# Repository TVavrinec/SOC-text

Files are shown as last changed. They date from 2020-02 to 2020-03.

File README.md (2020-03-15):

# SOC-text
samotný text SOČky je v .pdf ostatní soubory jsou pro výrobu tohoto .pdf (s názvem SOČ)
ve složkách jsou pak obrázky které jsou i v práci jako takové a ve složkách jsou samostatně opět pro výrobu souboru .pdf
v přílohách jsou pak podklady k výrobě obsahu práce (podklady k desce a mechanice robota)

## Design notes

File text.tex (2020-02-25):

% !TeX spellcheck = en_US
\documentclass{template/socthesis}

\usepackage{subcaption}
\usepackage{amsmath}
\usepackage{enumitem}
\usepackage{hyperref} % balíček pro hypertextové odkazy

\usepackage{color} % balíček pro obarvování textů
% \color{blue}
\usepackage{xcolor}  % zapne možnost používání barev, mj. pro \definecolor
\definecolor{mygreen}{RGB}{0,150,0} % nastavení barev odkazů 
\definecolor{myblue}{RGB}{0,0,200} 
\definecolor{commentgreen}{RGB}{0,100,0} % nastavení barev pro příklady z C++
\definecolor{deepblue}{rgb}{0,0,0.7}
\definecolor{deepred}{rgb}{0.6,0,0}
\definecolor{deepgreen}{rgb}{0,0.5,0}

\hypersetup{colorlinks=true, linkcolor=myblue, urlcolor=mygreen, citecolor=blue, anchorcolor = magenta,
	linktocpage = true, frenchlinks } % nastavení barvy odkazů 

%\addbibresource{text.bib}

\titlecz{Postav si svého prvního robota}
\titleen{Build your first robot}
\author{Tomáš Vavrinec}
\field{10}
\school{Střední průmyslová škola a Vyšší odborná škola Brno, Sokolská}
\mentor{Mgr.Miroslav Burda}
\mentorstatement{Mgr.Miroslava Burdy}

% Změňte, pokud se liší
%\region{Jihomoravský}
%\placefooter{Brno 2017}

\begin{document}

\maketitle

\makecopyrightstatement{V~Brně}

\makethanks{Děkuji svému školiteli Mgr. Miroslavu Burdovi za obětavou pomoc, podnětné připomínky a nekonečnou trpělivost, kterou mi během práce poskytoval.}

\pagestyle{empty}

\section*{Anotace}

Cílem práce je  vyvinout vhodnou levnou a rozšiřitelnou vzdělávací pomůcku -- řídící desku, která umožňuje názorně předvést vlastnosti senzorů a pohonů a která bude schopná řídit například i amatérské soutěžní roboty nebo školní ukázku výrobní linky. Dále vyvinout snadno dostupného robota, kterého tato řídící deska bude řídit.

Tato práce se zabývá návrhem a výrobou řídící desky Schoolboard a robota Schoolbot a jejich použitím při výuce dětí v zájmovém vzdělávání a při školní výuce předmětů elektroniky, automatizace, programování a dalších. 

\subsection*{Klíčová slova}
SchoolBot; SchoolBoard; robot; vyuka robotiky; řídící deska; ESP32

\vspace{20mm}

\section*{Annotation}

The aim of this work is to develop a suitable cheap and extensible educational tool -- control board, which allows to demonstrate the characteristics of sensors and drives and which will be able to control, for example, amateur competition robots or school demonstration production line. Further, to develop an easily accessible robot to control this control board.

This work concerns with the design and production of the control board named Schoolboard and Schoolbot robot and their use in teaching children in leisure education and in school teaching of electronics, automation, programming and others.

\subsection*{Keywords}
SchoolBot; SchoolBoard; robot; teaching robotics; control board; ESP32

\newpage
\pagestyle{plain}

\tableofcontents % vysází obsah

%%% Začátek práce
\setcounter{figure}{0}
\setcounter{table}{0}
\newpage

\chapter*{Úvod}
\addcontentsline{toc}{chapter}{Úvod} % přidá položku úvod do obsahu
Moje práce má za cíl vytvořit pomůcku (robota) pro praktické seznámení s~elektonikou, robotikou a programováním pro:  

\begin{itemize}
	\item účastníky volnočasových kroužků robotiky, elektroniky a podobných
	\item studenty středních škol, především oborů elektronika, automatizace, robotika, ale i pro předměty informatika nebo fyzika
	\item další začínající zájemce o elektoniku a robotiku. 
\end{itemize}

 Pokud zájemce -- začátečník  o elektroniku a nebo hobby robotiku absolvuje \uv{blikání ledkou}, obvykle chce pokračovat stavbou svého prvního robota (podle hesla: \uv{Ať se to hýbe!}). Když se 
 rozhlédne kudy dál, zjistí, že všechny dostupné možnosti jsou tak či onak dost problematické (viz kapitola \ref{konkurence}). 
 
 Podobná situace nastává ve škole, kdy například funkci probíraných senzorů, enkodérů a podobně někdy není na čem prakticky ukázat. To se týká především situace, kdy učitel chce, aby studenti s robotem sami pracovali, například ve dvojicích.   

Řídící deska \textbf{Schoolboard} a robot \textbf{SchoolBot} jsou primárně navrženy pro volnočasový vzdělávací kroužek robotiky pořádaný na naší škole a jsou určeny pro začátečníky. Jako takoví dávají účastníkům kroužku možnosti, které má prakticky každý soutěžní robot, konkrétně pohon pro pohyb na hřišti, klepeta pro manipulaci s herními prvky a senzory pro samostatnou orientaci na hřišti. 
\newpage

 Takový robot by měl mít: 

\begin{itemize}
	\item \textbf{modulární senzoriku} -- být schopný připojit na sebe různé senzory 
	
	\item \textbf{rozšiřitelnou konstrukci} -- možnost i velké úpravy, změn a rozšíření konstrukce robota, připojení různých pohonů (motory, serva)
	
	\item \textbf{bezdrátové řízení}
	
	\item dostatečně \textbf{tuhou konstrukci}
	
	\item  \textbf{možnost programovat v C++}, které je dnes standardem v této oblasti
	
	\item a hlavně: \underline{\textbf{nízkou pořizovací cenu}}, protože bez ní jsou všechny ostatní příznivé vlastnosti bohužel téměř na nic 
	
\end{itemize}

Ideálně by si takového robota účastníci kroužku měli být schopni postavit, spájet a oživit (podle pokynů vedoucího) sami. 

%\section{SchoolBot}

%\section{BlackBox}
%BlackBox je elektronicky ovládaný trezor, který je s vhodnou úpravou schopen i jezdit na vlastních kolech. Pro začátečníky má i čistě mechanickou variantu bez elektroniky, ta však muže sloužit jen jako trezor a nemá ostatní možnosti které má až elektronická varianta. Elektronická varianta má rozmanité senzory, díky kterým muže nabývat různých podob od trezor po hodiny.

\newpage

\chapter{Proč vytvářet vlastní roboty?}

Proč vlastně vytvářet vlastní elektroniku i mechaniku, když je na trhu tolik různých robotu a vozítek? Konkurenční roboti, kteří se běžně prodávají, jsou totiž většinou velmi drazí a často nemají ani moc možností. Například známé LEGO Mindstorms, u kterého se cena základní sady pohybuje nad sedmi tisíci korunami \cite{lego_cena},
 je vzhledem ke svým možnostem ohromně předražené.
 
%zmizela poznámka o dokumentaci (nebyla tak pravdivá jak bych chtěl abych jí zde nechal [ splnoval by to asi jen Asuro a možná OZOBOT s Edisnem])

\newpage

\section{Konkurence} \label{konkurence}

\subsection{LEGO Mindstorms EV3}

\begin{figure}[h]
	
	\centering
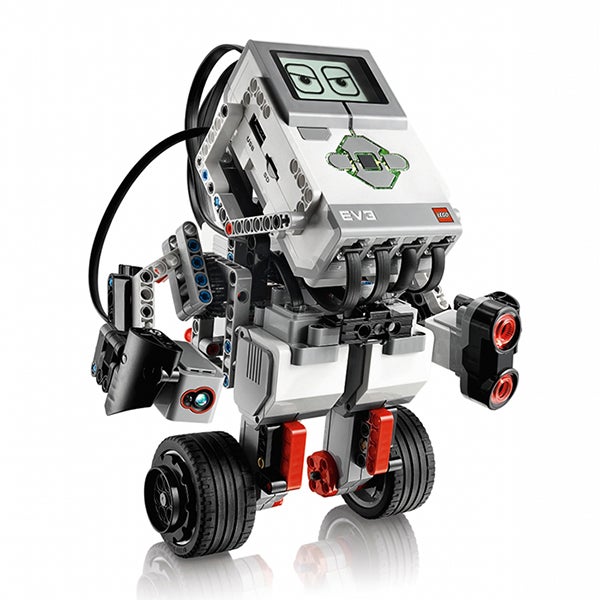
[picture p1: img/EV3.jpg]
	
	\caption{LEGO Mindstorm}~\cite{lego_obr}
	
\end{figure}

LEGO Mindstorms \cite{lego} je známé svou jednoduchostí. Základní roboti se s touto sadou dají sestavit velmi rychle, což poskytuje hlavně začátečníkům motivaci, neboť již s poměrně malým úsilím sestaví něco, co na první pohled funguje. Dílky LEGa však nejsou moc pevné a konstrukce z nich postavená jich tedy vyžaduje velké množství, aby byla obstojně tuhá. To se samozřejmě dá vyřešit tím, že si člověk udělá konstrukci z jiného materiálu, potom ale odpadá výhoda jednoduchosti stavby.

Možnosti robota se z velké části odvíjí od senzoriky. LEGO trpí na nedostatek senzorů a ještě vic na melí počet konektorů. Nejen, že v základní sadě je, krom tlačítka, od každého sensoru jen jeden kus. Ale ani kostka, řídící centrum LEGa, nedokáže číst víc než čtyři senzory naráz. Je pravda že LEGO má možnost spojovat několik kostek dohromady, to však samozřejmě vyžaduje mít jich víc, což je při ceně LEGa poměrně drahé.

LEGO má své vlastní programovací prostředí, které je většinou pro začá\-teč\-ní\-ky dobré. Jakmile však uživatel chce vytvářet vetší program, prostředí velmi rychle ztratí užitečnost. Vetší programy jsou v grafickém prostředí velmi nepřehledné. Navíc prostředí LEGa může být u větších programů nestabilní. Existují však i prostředí, ze kterých se dá lego programovat textově, například v jazyku C++, což je u složitějších programu přehlednější a také méně náročné pro počítač.

\subsection{Mbot} 

\begin{figure}[h]
	
	\centering
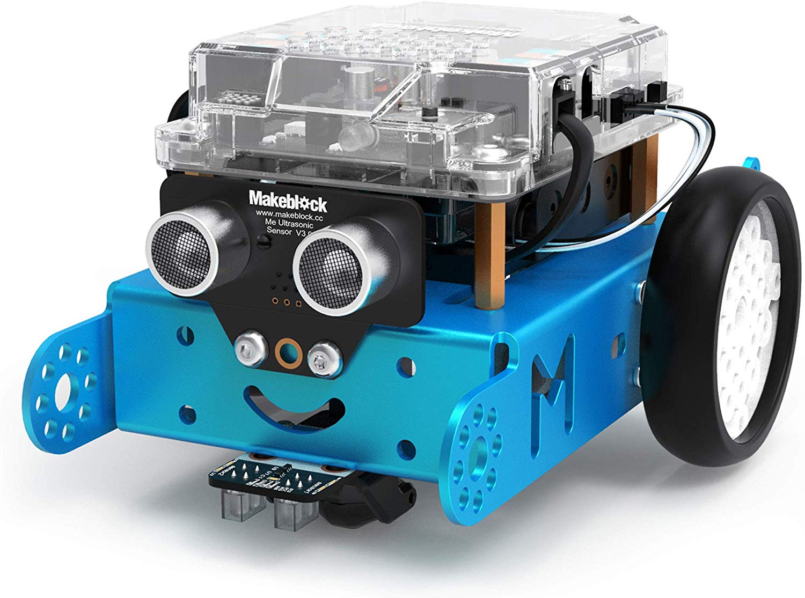
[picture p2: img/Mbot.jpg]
	
	\caption{Mbot} 
	\cite{Mbot_obr}
	
\end{figure}

Mbot \cite{Mbot} je oproti LEGu daleko levnější (cena se pohybuje kolem osmnácti set korun za kus) ale trpí stejným, nebo i větším, nedostatkem konektoru pro sensory. 

Co se konstrukce týče, problémy s pevností u Mbota není, ale zase se nedá snadno upravit. Konstrukce je totiž hliníková, což je v pořádku, pokud není potřeba konstrukci výrazně upravovat. Robota je ale většinou třeba přizpůsobit konkrétnímu užití.
 Ze zkušenosti se nejvíce osvědčilo dřevo, které se dá jednoduše upravovat bez větší námahy a zároveň není problém z něj udělat dostatečně tuhou konstrukci. Hliník se však tak lehce ručně upravovat nedá.
 
Mbot je založen na procesoru ATmega328, což je stejný procesor, jaký se používá i u velice známého Arduina.
To znamená, že některé programy, které jsou napsané pro Arduino, je možné spustit i zde.

\subsection{Edison V2.0}

\begin{figure}[h]
	
	\centering
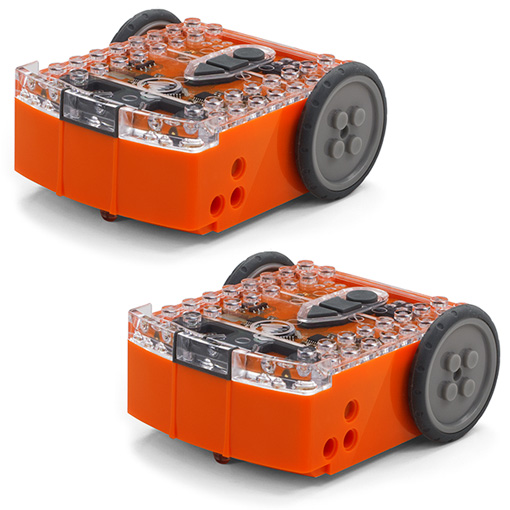
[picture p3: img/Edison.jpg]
	
	\caption{Edison V2.0} 
	\cite{Edison_obr}
	
\end{figure}

Edison \cite{Edison1}, \cite{Edison2} je velmi podobný LEGu a má i podobné problémy. Opět nedisponuje velkým počtem senzorů, ale oproti LEGu je alespoň daleko levnější \cite{Edison_cena}. 

Stejně jako LEGO má i Edison vlastní grafické programovací prostředí, bohužel jsem jej nikdy nepoužíval, ale vypadá velmi podobně jako prostředí LEGa. Myslím si proto, že stejně jako prostředí LEGa bude i toto velice dobré na malé prográmky pro děti, ale nevhodné pro obsáhlé programy.

Všechny senzory má Edison uvnitř sebe a nedají se proto dovést na místo, kde je uživatel nejvíc potřebuje. Uživatel se proto musí přizpůsobit rozložení senzorů na řídící jednotce, stejně tak se nedá vyvést ani nic jiného. Jediné, co se dá, je vyměňovat kola (například za nějaké ozubení) a pomocí toho si pak dovést náhon z motoru na potřebné místo.

\newpage

\subsection{OZOBOT }
\begin{figure}[h]
	
	\centering
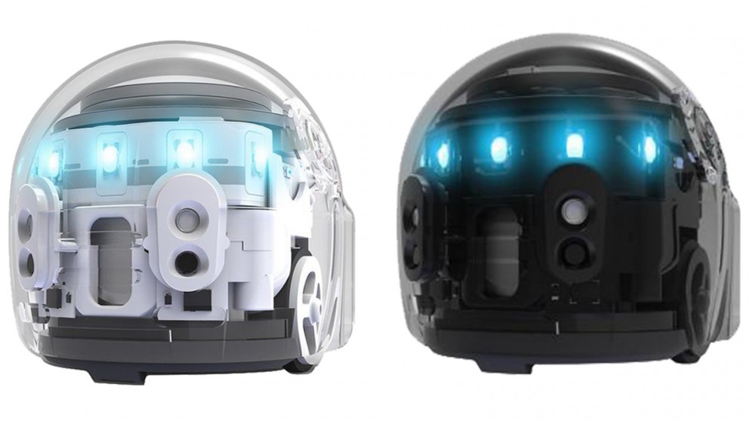
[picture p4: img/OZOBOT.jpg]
	
	\caption{OZOBOT 2.0} 
	\cite{OZOBOT_obr}
	
\end{figure}
Ozobot \cite{OZOBOT1}, \cite{OZOBOT2} je mini robot, z toho vyplývají jeho největší výhody i nevýhody. Například pochopitelně není dělaný na to, aby cokoli vozil nebo jakkoliv stěhoval. Téměř se nedá upravovat, na to ale opět není dělaný. Jeho účel je především jezdit po čáře a vykonávat příkazy na ní zapsané pomocí barevných vzorů. Přes to že se novější verze dají i programovat, jejich funkce jsou pořád mířené do velké míry právě na čáru a barevné příkazy na ní.

\newpage

\subsection{Asuro}
\begin{figure}[h]	
	\centering
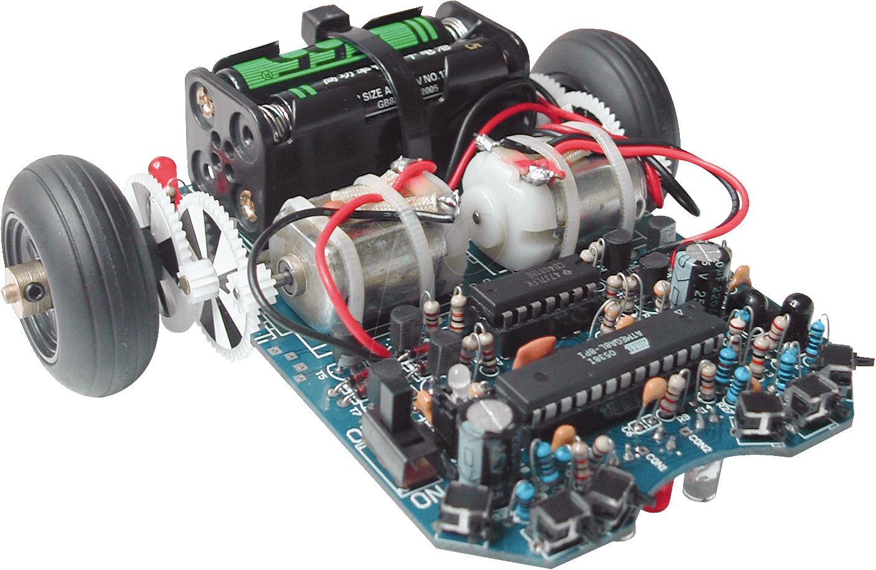
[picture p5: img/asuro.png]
	
	\caption{Asuro} 
	\cite{Asuro_obr}	
\end{figure}
Asuro \cite{Asuro_navod}, \cite{Asuro_cena} je robot postavený kolem základní desky. Jedná se o stavebnici, ale přesto nemá ani jednoduché pomůcky pro možnost přesné stavby. Asuro má mezi koly a motorem převodovku, která se ukládá do jakýchsi ložisek. Ta se bez jakéhokoli zapozicování napájí na plochu desky. Výsledkem je téměř nemožnost uložit kola převodovky přesně.

\newpage

\subsection{Microbit}
%\textbf

\begin{figure}[h]
		
		\centering
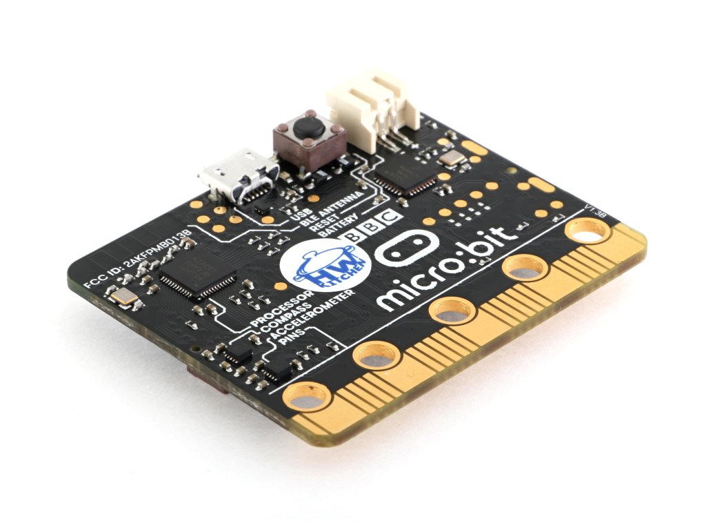
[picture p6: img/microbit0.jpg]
		
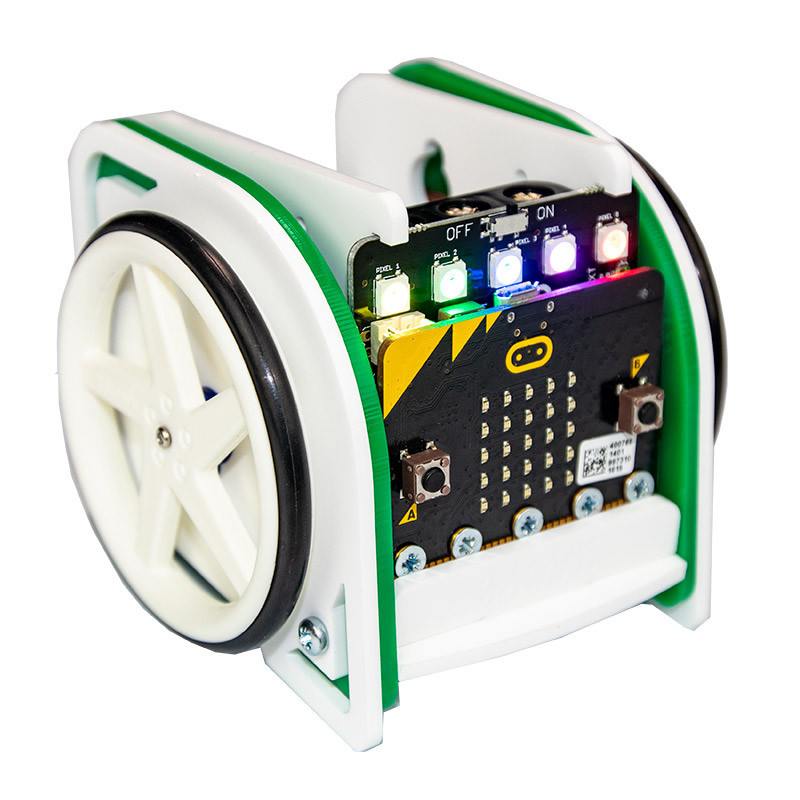
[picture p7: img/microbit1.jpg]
		
		\caption{Microbit \cite{Microbit_obr1}, \cite{Microbit_obr2}} 
		
\end{figure}

Microbit \cite{Microbit1}, \cite{Microbit2}, \cite{Microbit3} je především řídící deska se senzory a výstupními ledkami. Není to primárně vozítko, přestože existují konstrukce, které jsou určené právě pro řízení microbitem. Taková konstrukce však muže využívat pouze serva, nebo musí mít vlastní řízení motoru. Microbit totiž motory řídit edokáže sám, dokáže řídit jen serva, která si silové řízení řeší sama. Toto však není velký problém, protože existuje více různých konstrukcí, které právě toto řeší. 

Microbit má překvapivě docela dost senzorů přímo na základní destičce. Podle mých informací kompas, který je přímo na desce téměř nefunguje, ale vzhledem k tomu, co všechno na sobě malá destička Microbit má, to není až taková tragédie. Kompas je stejně často potřebné dostat co nejdál od zbytku robota, kvůli všemožnému rušení, takže by se i tak dost možná používal jako externí součástka.

Microbit má zároveň matici ledek, na které si uživatel muže zobrazovat, co se mu zlíbí a zároveň se jimi dá i měřit světelnost okolí. Používání led diod jako fotodiod sice není tak přesné, nicméně to jde a je to zajímavé řešení.

Microbit ale nemá zrovna velké množství pinu, které by se daly použít, a především je opět drahý. Cena čisté desky, bez jakéhokoli příslušenství, se pohybuje kolem 500 Kč a za tuto cenu jsem já schopen vyrobit desku, která je schopna operovat i se silovými výstupy (a ještě mi něco zbude).

\subsection{Shrnutí}
Komerční systémy jsou většinou velmi drahé, mívají nedostatek senzorů, mívají měkkou nebo obtížně upravitelnou konstrukci a také nemají moc velký výkon ani přesnost pohonu.

Možná si říkáte, proč mi záleží na tom aby robot pro začátečníky měl všechny tyto možnosti. Vždyť člověku, co nikdy robota nestavěl, by to mohlo být skoro jedno. Ano, ale já chci, aby se na prvním robotu, které si zájemce postaví, dalo stavět dál. Aby bylo vidět, že si z robota, který toho moc neuměl, může uživatel postavit něco, co by třeba mohlo jezdit na soutěže a vyhrávat.

\begin{table}[h]
	\centering
	\begin{tabular}{|l|l|l|l|l|l|l|}
		\hline
		\textbf{robot }			& modulární   & rozšiři- & bezdrátové  & tuhá  & nízká & C++\footnote{Možnost naprogramování robota v C++.} \\
		 & senzorika & telnost & řízení & konstrukce & cena &  \\
		 \hline
		Mbot 			& 0 				& 0 			& 0 			& 1 			& 0			& 0	\\ 
		LEGO\footnote{myšleno LEGO MINDSTORMS} 	& 1/2 				& 1 			& 1 			& 0 			& 0			& 1/2	\\ 
		Edison 			& 0 				& 0 			& 1/2 			& 1/2 			& 1			& 0	\\ 
		OZOBOT			& 0					& 0				& 1 			& 1				& 0			& 0	\\
		Asuro			& 0					& 0				& 0 			& 0				& 0			& 1	\\
		Microbit		& 0					& 1				& 1 			& 1				& 0			& 0	\\
			\textbf{SchoolBot} 		& \textbf{1} 				& \textbf{1} 			& \textbf{1} 			& \textbf{1} 			& \textbf{1} 		& \textbf{1}	\\ 
		\hline
	\end{tabular}
	\begin{center}
		\caption{Srovnání možností dostupných komerčních systémů pro hobby roboty}
	\end{center}
\end{table}

\chapter{SchoolBot}

SchoolBot je komplet, skládající se ze řady jednotlivých dílků, které nebudu popisovat samostatně, ale pro přehlednosti systém rozdělím na elektroniku a~mechaniku.

\section{Elektronika}

Elektronika je především řídící deska SchoolBoard kterou shrnuji v samostatné kapitole \ref{RB3202} a detailně rozebírám v přílohách. Krom desky obsahuje SchoolBot battery pack, motory s enkodéry a inteligentní serva LX15D
\cite{inteligentni_servo_LX15D}, která uvádí do provozu klepeta, nástroj pro manipulaci s objekty při soutěžích, především s herními prvky.

\begin{figure}[h]
	
	\centering
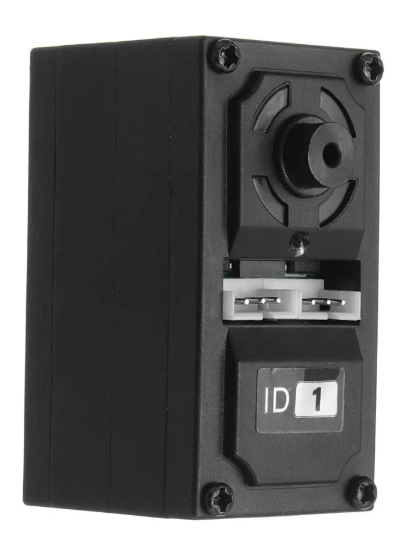
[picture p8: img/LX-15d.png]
	
	\caption{inteligentní servo LX-15d \cite{inteligentni_servo_LX15D}}
	
\end{figure}

\subsection{Battery pack}

Battery pack je sestaven ze dvou li-on baterií 18650, které jsou pomocí DPS spojeny v jeden celek. Připojení do robota je pak zajištováno pomocí dutinek a to každý článek zvlášť, serializují se až po vložení do robota. Důvodem pro vyvádění obou článku zvlášť je nabíjení. To je totiž realizováno pomocí lineárních nabíjecích modulu, které se napájejí z USB a každý článek se nabíjí zvlášť.

Aby se battery pack nedal omylem připojit s opačnou polaritou, je vyřešen tak, že se dá při připojení otočit dvěma způsoby a oba mají správnou polaritu, dokonce i stejné pořadí článků.

\begin{figure}[h]
	\centering
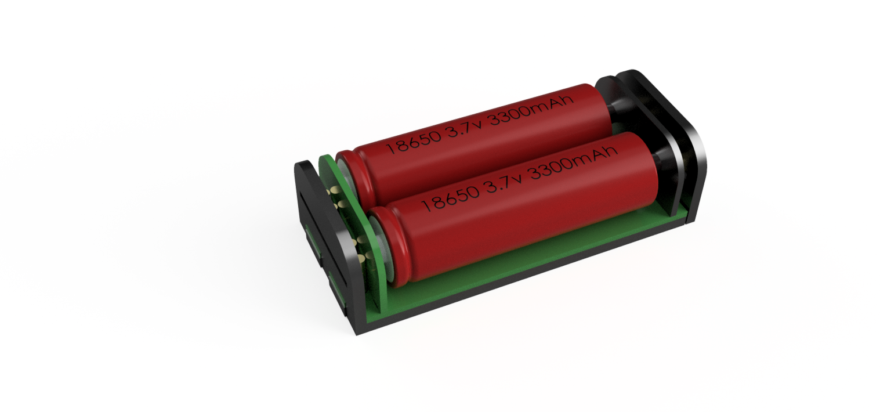
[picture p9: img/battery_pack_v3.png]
	
	\caption{render 3D modelu battery packu}
\end{figure}

\subsection{Motory s enkodéry}

SchoolBot používá levné motory s plastovou převodovkou, které v základu enkodéry nemají. Enkodéry si proto SchoolBot řeší sám, a to pomocí magnetu a dvou Halových sond. Takto vyrobený inkrementální enkodér pak vyhodnocuje procesor na řídící desce.

\newpage

\section{Mechanika}

Mechanika SchoolBota je celá z překližky vypálené pomocí laserového řezáku. Je stavěná kruhově, aby se robot nemohl zaseknout v nějakém rohu a~v~přední části má umístěná klepeta, kterými je robot schopen nabírat a převážet různé objekty. 

\subsection{Uložení kol a motoru}

Kola nejsou jen tak nasazená na motor. Aby se nevyvracela, a tím pádem méně zatěžovala převodovku motoru, jsou z druhé strany podepřena a uchycena k obvodu konstrukce.

Celý motor i s kolem je pak zčásti držen podporou kola, ale především je celý motor vložen do těsné šachty, kde se nemůže otočit ani posunout jiným směrem než vzhůru. Následně je přitlačen palubou, která se přišroubuje čtyřmi šrouby. Takovéto řešení umožnuje jednoduchý přístup k motoru a jeho pevné uchycení.

\begin{figure}[h]
	\centering
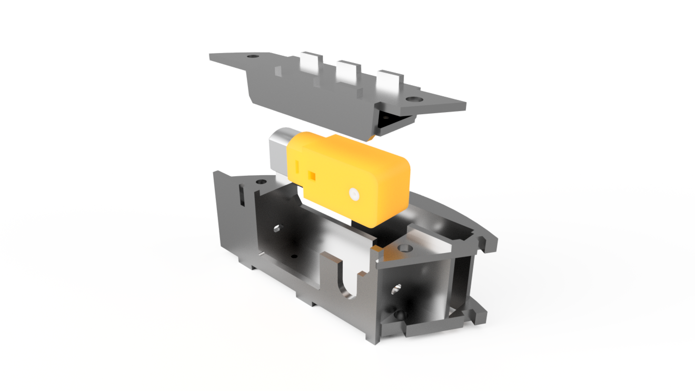
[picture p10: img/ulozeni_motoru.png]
	
	\caption{render 3D modelu motorového lože}
\end{figure}

\newpage

\subsection{Klepeta}
Klepeta jsou postavena tak, aby měla osu otáčení co nejdále od sebe. Protože ve chvíli, kdy robot s otevřenými klepety narazí do mantinelu, musí mít konce klepet k sobě blíž než osy jejich otáčení, aby se klepeta sama zavřela (o mantinel bez potřeby řízení). Z tohoto důvodu jsou serva, na kterých jsou klepeta uložena, posazena co nejdál od sebe, právě aby se klepeta mohla otevřít co nejvíc a u toho si zachovat svojí schopnost zavřít se o mantinel (stěnu).
\begin{figure}[h]
	\centering
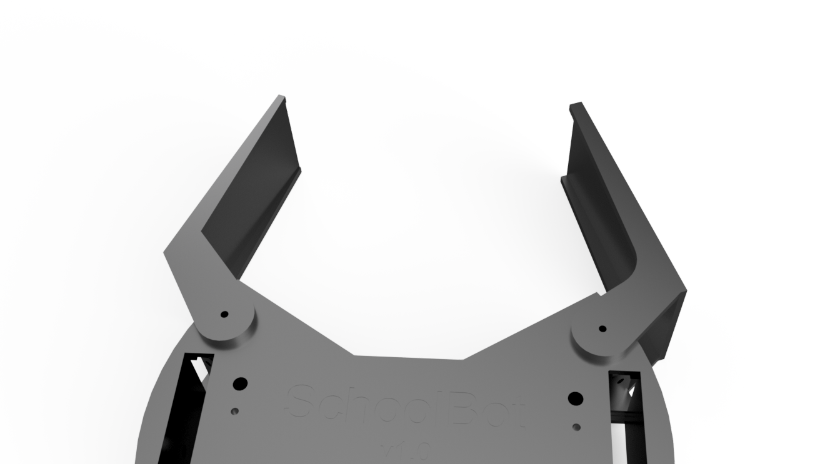
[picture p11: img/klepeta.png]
	
	\caption{renderovaný pohled na klepeta}
\end{figure}

\chapter{SchoolBoard}\label{RB3202}

\ref{RB3202_obr}

\section{Popis desky}

Deska \ref{RB3202l} %todo
má k dispozici

\begin{itemize}
	\item třicetidvoubitový procesor ESP32 s taktovací frekvencí 240~MHz 
	a~na\-pá\-je\-cím napětím 3,3 V 
	\item flash pamětí 4 MB (dělají se i verze s 8 a 16 MB), 520 KB SRAM, WI-Fi, Bluetooth, 28 vstupně výstupních piny, dva ADC převodníky (jeden s 6 piny a druhý s 10 piny), jedním DAC převodníkem s dvěma piny, tři UARTy, dvě SPI, tři I2C(jedno je použito interně pro flash) atd.
	
	\item Motorový driver DRV8833, který umožnuje řídit dva stejnosměrné motory nebo jeden krokový motor.
	
	\item Tři konektory na inteligentní serva LX-15D nebo LX-16A. Deska dokáže řídit až 254 těchto serv. Serva se totiž dokáží řetězit za sebe, ale pokud potřebují větší proud (když podávají větší kroutící moment), ubytek napětí na kabelech je už moc velký, aby serva mohla využít plný výkon. Proto jsou na desce konektory tři a ne jen jeden.
	
	\item Čtyři uživatelská tlačítka.
	
	\item Tři uživatelské LED a jedna LED signalizující zapnutý stav.
	
	\item Možnost měření napětí baterie.
	
	\item Hardwarové řešení startu a vypínání (dá se použít i jako nouzový vypínač). Tlačítka na zapínání a vypínání jsou jak přímo na desce, tak jsou i vyvedena na pinheady pro možnost připojení externího řízení.
	
	\item Konektor na připojení motorů s enkodérem.
	
	\item Deska operuje na napětí 3,3~V, ale aby byla schopná komunikovat i s periferiemi operujícími
	na napětí 5~V, jsou čtyři piny opatřené převodníkem napěťových úrovní.
	Piny IO35, IO32, IO14 a IO12 jsou tedy schopny operovat jak na napětí 3,3~V, tak na 5~V.
	
	Piny jsou teoreticky schopné pracovat i na napětí vyšším, záleží na součástce IM3
	(step-down nebo stabilizátor 7805), která napájí pře\-vod\-ník. Pokud bude IM3 dodávat jiné napětí, bude toto napětí i na 5~V pinech (napětí nesmí klesnout pod 4,5~V jinak procesor nedostane dost proudu).
	
	\item Vyvedení 5~V napájení je na oddělené stabilizaci (součástka IM4) pro možnost napájení jiným napětím.
	
	\item Deska má také vyvedeny všechny piny ESP32, které nejsou spojeny 
	s~hlavní funkcí desky (řízení motorů) a není problematické se o ně starat při bootu ESP32.
	
	\item Schoooboard je možné řetězit a tím pro robota nebo jiné zařízení získat  jednak další výpočetní výkon, jednak další možnosti rozšíření. 
	
	\end{itemize}

\section{Možné periferie}
Vzhledem k tomu že je deska řízena procesorem ESP32, který umožnuje komunikaci po řadě sběrnic a disponuje i svým vlastním AD převodníkem. Je schopna pracovat s velmi rozsáhlou řadou periferií. Díky převodníku na\-pě\-ťo\-vých úrovní navíc umožnuje komunikaci ne jen na 3,3~V (pracovní napětí procesoru) ale i na napětí 5~V (při jiném nastavení jisté součástky[viz přílohy \ref{RB3202-5V}]
 i~jiném napětí vyšším než 3,3~V). 
\subsubsection{Příklady možných senzorů}
\begin{itemize}
	\item Kamera
	\item Ultrazvukový dálkoměr
	\item Infračervený dálkoměr
	\item Laserový dálkoměr
	\item Senzory na sledování čáry
	\item Senzory barev
	\item Gyroskop
	\item Akcelerometr
	\item Kompas
	\item Hodiny reálného času
	\item Teploměr
	\item Barometr
	\item Senzor osvětlení
	\item Vlhkoměr
	\item a mnoho dalších ... 
\end{itemize}

\subsubsection{Příklady jiných periferií}

\begin{itemize}
	\item Inteligentní serva (např. LX15D nebo LX16A)
	\item Inteligentní LED (např. WS2812)
	\item Modelářská serva
	\item Stejnosměrné motory (s rozsahem napětí od 6 do 11~V a proudem do 1~A [při použití silnější verze stejného driveru do 1,5A])
	\item Krokový motor
	\item Obyčejné LED
	\item Elektromagnetické ventily
\end{itemize}

\section{Vývoj}

SchoolBot jsem začal vyvíjet, protože účastníci kurzu robotiky v minulých letech nestíhali za jeden školní rok vytvořit vlastní konstrukci a ještě ji naprogramovat. Přesto, že elektroniku již vyřešenou měli, tak mechanika a~především programování na ně bylo stále příliš. Přitom robotické soutěže jsou \uv{zlatým hřebem} každého školního roku. Proto jsem začal koncem loň\-ské\-ho školního roku 2018/2019 vyvíjet robota, který měl řešit jak elektroniku, tak většinu mechaniky. 

První prototyp mechaniky byl hotový již začátkem letních prázdnin, ale další vývoj pokračoval až o hodně později. První verze totiž vyžadovala jen velmi málo úprav jsem musel dokončit řídící desku, která již sice také měla první prototyp za sebou, ale vyžadovala daleko víc úprav. Již druhá verze desky byla plně provozuschopná a začátkem školního roku 2019/2020 jsme jí začali stavět s účastníky kurzu.

 Ne všichni však chtěli použít mojí konstrukci. Někteří si jí chtěli navrhnout sami a někteří měli tak těžké doplňky, že by je tento robot neuvezl. 
SchoolBota tak letos využil jen jeden ze sedmi týmů.

\section{Kde se deska používá}
Deska se používá ve dvou volnočasových kurzech robotiky a při výuce elektrotechniky a automatizace na naší škole.

\subsection{Školní kroužek robotiky}

Ve školním kurzu robotiky se začalo pracovat se SchoolBoardem koncem října. Účastníci si nejprve zapájeli %(jelikož první verze SchoolBoardu se ještě neosazovala strojově) 
desku a v prosinci si začali navrhovat a~stavět mechanickou konstrukci robota. V té době již byli rozděleni do týmů na soutěž Robotický Den \cite{RD2020}
 v Praze a měli vybranou disciplínu, které se chtěli zúčastnit. Tím pádem již mohli vyvíjet konkrétní instrumenty pro konkrétní úkoly a nemuseli vymýšlet univerzální systémy, které jsou náročné na mechaniku, a především na programování. Díky těmto znalostem některé týmy došly k názoru, že si musí konstrukci opravdu navrhnout samy a nemůžou použít SchoolBot. Robot jednoduše není dost silný, aby uvezl předměty, které samy váží více než dva kilogramy.

Tímto způsobem vzniklo v šesti týmech pět různých robotů, jeden tým (ten šestý) zůstal u SchoolBotu a svou vlastní konstrukci tak nevytvořil. Všichni tito roboti však jsou řízeni SchoolBoardem. 

V jednom případně dokonce dvěma Schoolboardy, protože týmu nestačily dva motory a protože v týmu měli víc desek.

Jejich výsledky ze soutěže bohužel zatím nemám k dispozici protože soutěž se koná až 6 a 7.6.2020 a je tím pádem pro mě ještě v budoucnosti.

\begin{figure}[h]
	\centering
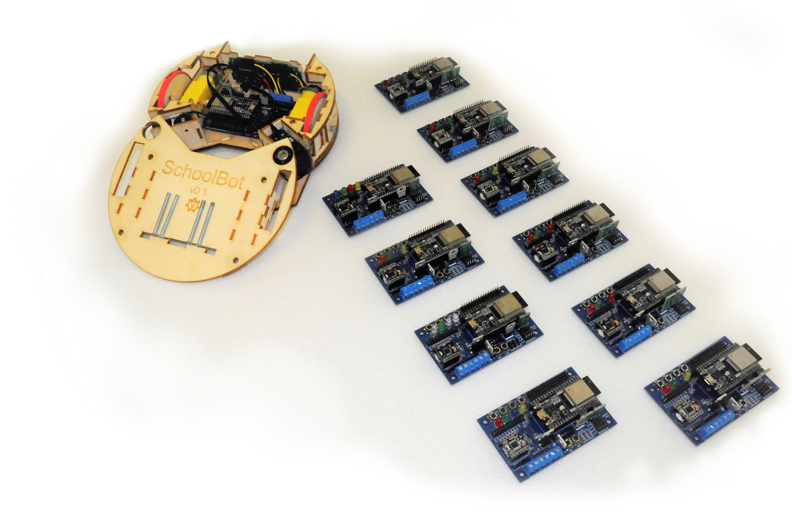
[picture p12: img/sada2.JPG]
	
	\caption{desky z kroužku a SchoolBot}
\end{figure}

\subsection{Kroužek na DDM Helceletova}

Na DDM Helceletova, sekce Robotárna se deska Schoolboard používá v kroužku \textit{Robotika pro středoškoláky}.

\subsection{Výuka}

Schoolboard i Schoolboard se používá na naší škole jako pomůcka pro výuku elektoniky  a~automatizace.

\subsection{Webové stránky ohledně Schoolboard}

Na webu \url{www.jesper.cz} je deska Schoolboard prezentována pod obchodním názvem \textit{Jesper} a budou zde k ní vždy aktuální informace a návody k práci.

\chapter*{Závěr} 

Cílem mé práce bylo  vytvořit pomůcku (robota) pro praktické seznámení s~elektonikou, robotikou a programováním pro zájemce z řad začínajících elektroniků a robotiků, použitelnou také  ve  školní výuce.   

Mnou navržená a vyrobená elektronika (deska Schoolboard) i konstrukce robota (Schoolbot) splňuje všechny požadované parametry: 

\begin{itemize}
	\item modulární senzoriku
	
	\item rozšiřitelnou konstrukci
	
	\item bezdrátové řízení
	
	\item dostatečně tuhou konstrukci
	
	\item  možnost programovat v C++
	
	\item \textbf{nízkou pořizovací cenu}
\end{itemize}

Deska i robot se již používá ve dvou volnočasových kurzech robotiky a~při výuce na naší škole. 

\vspace{0.5\baselineskip} % polovina výšky řádku
V současnosti je navržená vylepšená verze desky, která obsahuje navíc gyroskop, akcelerometr a komunikaci pro sběrnici 485. 

\vspace{0.5\baselineskip} % polovina výšky řádku
Do budoucna mám v plánu tuto vylepšenou desku vyrábět a  nabídnout
ji na \url{www.jesper.cz} dalším zájemcům. 

\appendix
\addcontentsline{toc}{chapter}{Přílohy}
	
%\chapter{Popis funkce jednotlivých součástek}

\chapter{Řídící část}
	\label{RB3202l}
	%\ref{RB3202s}
	\section{DEVKIT C}
	Procesor ESP32 je v tomto případě osazený na devkitu C \cite{DevKitC}.
	Je to malá deska, která se stará o potřeby procesoru a~dá se koupit jako celek. Zajišťuje jednoduché programování přes USB, zajištuje stabilizované napětí 3,3~V pro ESP32 a 3,3~V větev na desce a~stará se o výchozí hodnoty na pinech, u~kterých je to potřeba.

	Seznam důležitých pinů (viz schéma desky v příloze %todo \ref{RB3202sch}
	-- obrázek C.2 a~datasheet \cite{DevKitC}): 
	\begin{itemize} 
	\item EN – reset pin, pokud je na něm logická 0, ESP32 se resetuje, v~normálním stavu na něm má být logická 1, proto je zde pull-up rezistor, který zajištuje logickou 1.
	
	\item Piny s označením reserv AD1 jsou vyhrazené pro externí použití 
	a~nejsou tedy na desce nijak zapojené, jsou to piny, na které je připojený 
	první AD převodník ESP32 (ADC1), ADC1 je plně k užití pro uživatele na rozdíl 
	od ADC2, který je využíván Wi-Fi. ADC2 je tedy uživateli k~dispozici, jen pokud jej zrovna nevyžaduje Wi-Fi.
	
	\item Piny s označením AD1 jsou také piny ADC1, ale jsou interně připojené na některé periferie, která však nemusí být použité.
	
	\item IO34 -- pin použitelný na měření napětí na baterii přes jumper JP2 přímo na desce
	\item IO35 -- pin řídící inteligentní serva
	
	\item piny IO32, IO33 jsou připojené na převodník napěťových úrovní pro možnost komunikovat na 5~V. Analogové měření je ovlivněno pull-up rezistory na převodníku napěťových úrovní. Při potřebě užití těchto pinů jako analogových vstupů tedy doporučuji odebrat tyto pull-up rezistory. 
	
	To znamená, že tyto piny budou potřebovat softwarové pull-upy při užití jako vstupní pin při 5~V komunikace.
	
	\item Piny s rudým označením THIS SIGNAL MUST BE HERE, jsou lehce problematické, protože ovlivňují boot ESP. Musí na nich tedy při bootu být správná logická hodnota, jinak by ESP mohlo třeba bootovat z jiné paměti nebo by třeba USB nemohlo zapisovat do paměti pro program. Piny IO0 a IO2 nejsou vyvedeny a je o ně interně postaráno, pin IO12 je ale vyveden a uživatel si tedy musí dát pozor, aby na něm neměl při bootu logickou 1. Pokud zůstane nepřipojen, deska se o něj postará.
	
	\subsection*{LEVEL SHIFTER:}
	Neboli převodník napěťových úrovní zajištuje možnost digitální komunikace s 5~V periferií pro čtyři piny ESP. Konkrétně pro piny IO32, IO33, IO14, IO12.
	\item IO32 – jeden z pinů ADC1, podrobněji u DEVKIT C.
	\item IO33 – jeden z pinů ADC1, podrobněji u DEVKIT C.
	\item IO14 – jeden z pinů ADC2. ADC2 je využíván Wi-Fi. Jinak není použit.
	\item IO12 – je nutno odstranit pull-up (na součástce převodníku). IO12 volí paměť,
	ze které se bootuje a jestli do té správné jde nahrát program. Jinak není interně použit.
	\item Všechny čtyři piny jsou jinak vyvedeny i ve variantě 3,3~V.
	\item Převodník napěťových úrovní převádí logickou 1 pomocí pull-upů, tím pádem periferie pomocí převodníku spojené musí mít vstup s vysokým odporem, protože pokud by piny těchto periferií neměly velký odpor, tak by výsledek po dělení děliče vzniklého z pull-upu a periferie, která signál měří, mohl být pod rozlišovací schopností dané periferie.
	
	\section{Ostatní součástky na desce}
	
	\paragraph{D2}
	Dioda sloužící k zamezení napájení 5V větve z USB.
	Ochrana před přetížením napájení z USB.
	
	\paragraph{RN3A, B, C, D}
	rezistorová síť, odpory k LED
	
	\paragraph*{RN2A, B, C, D}
	rezistorová síť, ochranné odpory ke tlačítkům, aby 
	byl procesor chráněn při případné chybě 
	v programu.
	
	\paragraph*{SW0, 1, 2, 3}
	uživatelská tlačítka
	
	\paragraph*{C3, 4, 5, 8}
	kondenzátory pro vyhlazení signálu z tlačítka při stisknutí
	
	\paragraph*{JP4, 9}
	Vyvedení tlačítek a LED ven z desky pro možnost	
	vyvedení dál od desky, např. deska muže být v útrobách robota, ale tlačítka a ledky mohou být 
	pořád pohodlně dostupné, protože jsou vyvedené	
	někam na povrch stroje.
	
	\paragraph*{LED0, 1, 2}
	LED pro možnost signalizace různých stavů programu
	
	\paragraph*{Led3}
	powerLED -- signalizace, zda je deska zapnutá nebo vypnutá
	
	\paragraph*{JP6, 12}
	konektor pro připojení motoru s encoderem
	\item Vnější piny – napájení motoru
	\item Piny vedle vnějších pinů – napájení encoderu
	\item Vnitřní piny – signály encoderu
	\item Konektor je primárně určen pro inkrementální magnetické encodery, s~nimi i počítají programové knihovny
	
	\paragraph*{JP5}
	vyvod 3,3~V napájení
	
	\paragraph*{JP8, 11}
	Vyvedení některých pinů ESP, každý pin je vyveden alespoň dvakrát pro možnost připojení osciloskopu pro příjemnější hledání chyb programu.

	\paragraph*{JP1, 3, 7}
	vývody zpětivoltovaných pinu a jejich napájení
	\item \label{RB3202-5V} Napájení 5~V nemusí být nutně 5~V, tyto piny mají vlastní stabilizaci napájení (IM3), a tím pádem záleží na tom, jak je tato stabilizace nastavená. Deska je primárně navržená pro dva způsoby stabilizace: 
	step-Down a stabilizátor řady 7805:
	\begin{itemize}
		\item Step-Down má výhodu většího proudu, a hlavně nastavitelného napětí na výstupu. Naopak nevýhoda je nutnost nastavit požadované napětí a konkrétně u mnou používaného exempláře poměrně velký rozkmit výstupního napětí při změně odběru proudu.
		
		\item 7805 má výhodu napěťové stability naopak nevýhodu maximálního možného odebíraného proudu který závisí na vstupním napětí. Co se regulace napětí týče, v mnou použitém zapojení se napětí regulovat nedá.
	\end{itemize}

	\paragraph*{R5}
	Trimr sloužící jako dělič napětí baterie pro možnost měření jejího napětí. 
	\textbf{Před použitím nutno nastavit na vhodnou dělící hodnotu vzhledem k použitým bateriím!} Na výstupu z děliče nesmí být při plně nabité baterii víc než 3,6V. Pokud se při daném použití desky nemá měnit maximální napětí na baterii (počet článků baterie nebo jejich druh), doporučuji nastavit trimr jednou a následně jej zalepit, aby se například vibracemi nemohl rozladit.
	
	\paragraph*{JP2}
	jumper pro možnost odpojení měření baterie za účelem uvolnění analogového pinu IO34. Zároveň se dá použít na měření výstupu z děliče před jeho zapojením k ESP.
	
	\chapter{Silová část}\label{RB3202s}

	\section{Power manager}
	
	\paragraph*{X4}
	Svorkovnice pro připojení zdroje s napětím 7-11V. X4-1 je záporný pól a X4-2 je pól kladný.
	\paragraph*{Q5}
	MOSFET tranzistor typu P na ochranu proti přepólování
	
	Můžete si všimnout, že ochranná dioda uvnitř tranzistoru směřuje po směru proudu, a ne proti směru, což by bylo normální zapojení MOSFET tranzistoru.
	Tranzistor je zapojen takto právě z toho důvodu, že slouží jako ochrana proti náhodnému přepólování zdroje. Kdyby byl naopak, tak by sice při správné polaritě zdroje proud propustil a deska by byla napájena, ale v případě přepólování by proud propustil (skrz diodu) také, sice s ubytkem napětí na diodě, ale přes to by proud prošel a spálil by vše, co je citlivé na změnu polarity.
	\paragraph*{Q2}
	MOSFET tranzistor typu P, který umožnuje zapínání a vypínání desky
	\paragraph*{R3}
	Pull-up na bateriové napětí pro dráhu START~GATE1
	\paragraph*{Q6}
	MOSFET tranzistor typu N řídící tranzistor Q2
	\paragraph{R2}
	Pull-up na 3.3V pro dráhu OFF
	\item V zapnutém stavu drží na dráze OFF 3.3V
	(ne úplně čisté napětí ze stabilizátoru na ESP kvůli pull-downu R1) a tím otvírá tranzistor Q6, který zas drží otevřený tranzistor Q2.
	
	\paragraph*{R1}
	Pull-down pro dráhu OFF
	\item Tento rezistor je zde pro plné definování dráhy OFF,
	a to i ve stavu, kdy ESP není zapojeno, tím pádem by dráha nebyla jasně určena.
	
	\paragraph*{SW5}
	Tlačítko, které připíná dráhu OFF k zemi, a tím zavírá tranzistor Q6, čímž vypíná desku.
	
	\paragraph*{SW1}
	Tlačítko připínající dráhu ON k zemi, čímž skrz kondenzátor C1 a tranzistor Q2 zapne stabilizátor na DEVKIT-C, který pomocí rezistoru R2 otevře tranzistor Q6, který otevře Q2. 
	
	\paragraph*{C1}
	Kondenzátor, který se nabije při stisku tlačítka SW4, čímž na dobu nabíjení přivede na dráhu START~GATE zem a tím krátkodobě otevře tranzistor Q2. Přes Q2 projde proud, který pomocí stabilizátoru na DEVKIT-C vytvoří 3,3V, skrz pul-up R2 otevře tranzistor Q6 a ten trvale otevře tranzistor G2.Deska je v tu chvíli zapnutá.
	
	\paragraph*{R4}
	Rezistor pro vybíjení kondenzátoru C1
	
	\paragraph*{JP6}
	Konektor, pro možnost vyvedení vypínaní, zapínání, resetu 
	a~kontrolní powerledky na externí ovládání.
	
	\paragraph*{Obvod jako celek}
	Po připojení zdroje s napětím mezi 7 až 11V se při špatné polaritě napětí nedostane skrz tranzistor Q5. Deska sice nejede, protože nemá napájení, ale je chráněna před zničením opačnou polaritou. Při správném připojení zdroje, napětí projde skrz Q5 a tím pádem je na drahách BAT~POL+, START~GATE1 a ON napětí zdroje, na VCC se napětí nedostane, protože tranzistor Q2 je zavřen. Při stisku tlačítka SW4 se na dráhu ON dostane zem, tím pádem se kondenzátor C1 nabije a při nabíjení krátkodobě otevře tranzistor Q2. V době, kdy je tranzistor Q2 otevřen, skrz kondenzátor C1, se pomocí stabilizátoru osazeném na DEVKITu-C vytvoří napětí 3.3V. Skrz pul-up R2 se dostanou 3.3V na dráhu OFF a tím pádem na Gate tranzistoru Q6, který se v tu chvíli otevře a trvale přivede zem na dráhu START~GATE1. V tuto chvíle je tranzistor Q2 trvale otevřen, až do doby, kdy se na dráhu OFF nepřivede zem, v tu chvíli se zavře tranzistor Q6 protože má na Gate stejné napětí jako na Source (oba piny je připojené k zem). Pokud je Q6 zavřený zbývá jen možnost připojení země odjinud, pokud uvažujeme tento obvod bez poškození nebo jakéhokoli doplnění. Skrz rezistor R3 je dráha START~GATE1 připojena na zdrojové napětí, tím pádem je tato dráha tahána ke kladnému pólu a na k pólu zápornému, což by bylo potřeba pro otevření tranzistoru Q2, tímto způsobem se tedy Q2 určitě neotevře.
	START~GATE1 je dále připojen na rezistor R4 a kondenzátor C1 které jsou dále připojeny na přes tlačítko SW4 k zemi. Pokut je tedy tlačítko SW4 spojeno se zemí je zem i na dráze ON, v tuto chvíli je sice na dráhu 
	STERT~GATE1 skrz R4 připojena zem, ale vzhledem
	k tomu že R4 má desetkrát větší odpor než R3, který spojuje dráhu START~GATE s bateriovým napětím, na Gate tranzistoru Q2 pořád nebude dostatečně malé napětí, aby se Q2 otevřel. C1 propustí proud jen po dobu jeho nabíjeni a tím pádem se skrz nej nedá deska udržet trvale otevřená, dá se jím jen zapnout. To znamená že pokud procesor napíše na pin připojený na dráhu OFF, IO13, logickou nulu, deska se vypne, bez ohledu na to, jaké tlačítko člověk drží. Vypínání ne nutně platí pro 3.3V větev která je napájena jak z baterie tak z micro-USB na DEVKITu-C, takže pokud je procesor připojen k počítači pravděpodobně za účelem programování procesor a vše co je napájené z 3.3V je nadále funkční. Pokud USB není zapojeno, pak se při stisku SW5 nebo zápisu logické 0
	na pin IO13 deska jednoduše kompletně vypne.
	
	\section{Ostatní součástky na desce}
	
	\paragraph*{IM10}
	Motorový driver, DRV8833, na řízení dvou stejnosměrných motorů v napěťovém rozsahu 2,7 až 11V a maximálním proudem 1,5A. 
	Driver je také schopný místo dvou stejnosměrných motorů řídit jeden krokový motor.
	DRV8833 má pět vstupních řídících pinů: čtyři IN piny (dva pro každý motor) a sleep pin.  Podle IN pinů se řídí výstup - viz tabulka.
	Sleep pin uvádí driver do sleep módu pokud je připojen k zemi. Sleep mód slouží uživateli k úspoře energie v době, kdy nepotřebuje ovládat motory (po dobu aktivního sleep modu zůstanou motory pochopitelně vypnuté).
	
	\begin{table}[h]
		\centering
		\begin{tabular}{|l|l|l|l|l|}
			\hline
			xIN1 & xIN2 & xOUT1 & xOUT2 & FUNCTION \\ \hline
			0 & 0 & Z & Z & Coast/fast decay \\ 
			0 & 1 & L & H & Reverse \\ 
			1 & 0 & H & L & Forward \\ 
			1 & 1 & L & L & Brake/slow decay \\ 
			\hline
		\end{tabular}
		% zdroj!!!!!!!
		\caption{}
	\end{table}
	\newpage
	\paragraph*{X1, X2}
	Svorkovnice na silové vývody k motorům.
	
	\paragraph*{IM3}
	Step-down/stabilizátor pro 5V větev
	\item 5V napájí ESP, tím pádem i celou 3.3V větev skrz DEVKIT C
	\item Napětí, které je, zde je zároveň i napětí, na kterém komunikují 5V piny, proto doporučuji sem dát stabilizátor 7805, u kterého nemusíte hlídat napětí.
	
	\paragraph*{IM4}
	Step-down/stabilizátor pro napájení 5V pinů na 5V piništi.
	
	\paragraph*{JP42, 47, 48}
	Konektory pro připojení inteligentních serv.
	\item Navrženo pro serva LX-16A a LX-15D
	
	\paragraph*{C6}
	Velký elektrolytický kondenzátor jako zásobárna proudu při náhlé změně odběru.
		
	\paragraph*{D3}
	Zpětná dioda pro případ napěťové špičky, která by krátkodobě převrátila polaritu. V takovém případě se dioda otevře a proud propustí skrz sebe místo, aby protekl jinudy a přitom něco zničil.
	
	\end{itemize}

\chapter{Obrazová příloha}

\begin{figure}[h]
	\centering
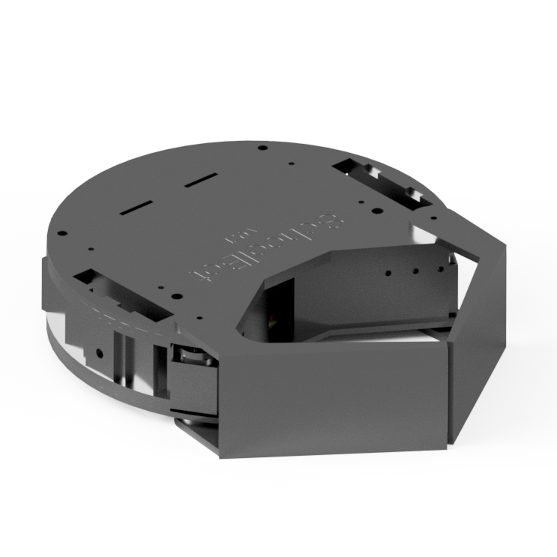
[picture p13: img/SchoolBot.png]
	
	\caption{render 3D modelu SchoolBota}
\end{figure}

\begin{figure}[h] 
	\centering
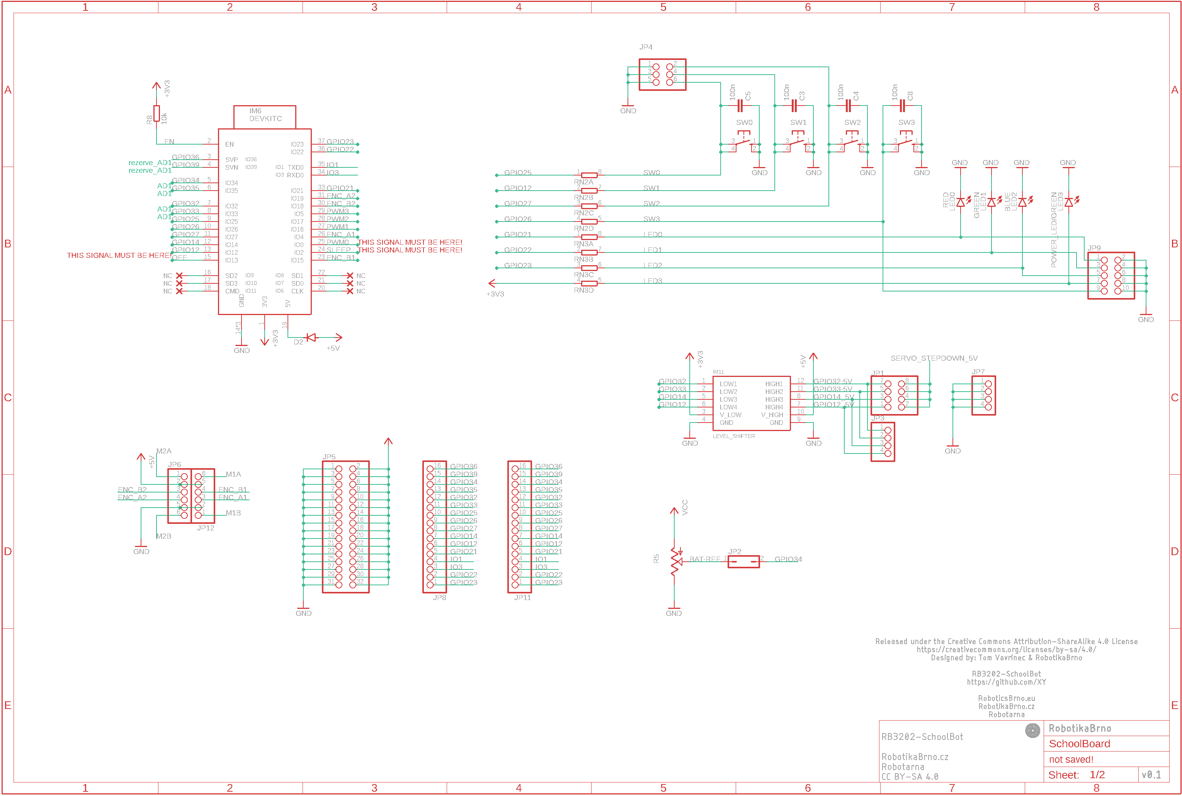
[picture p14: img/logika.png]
	
	\caption{schéma logické části desky}
\end{figure} \label{RB3202sch}

\begin{figure}[h]
	\centering
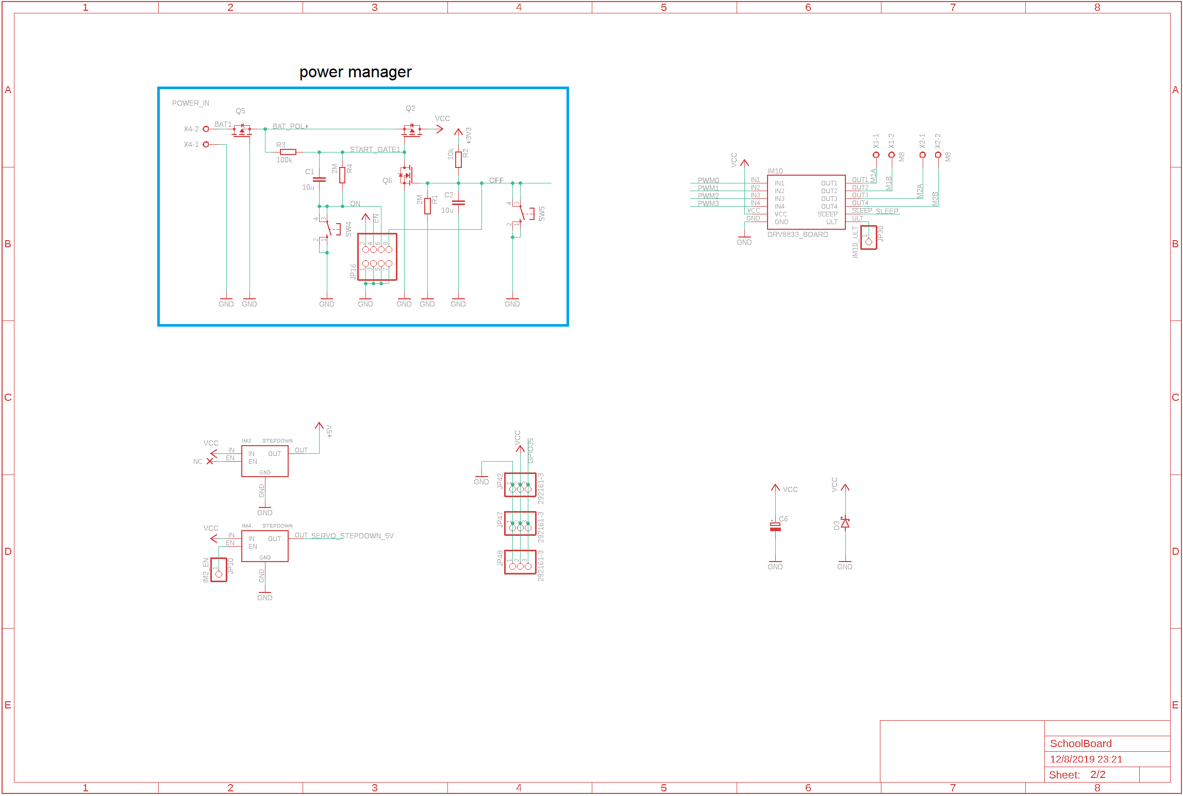
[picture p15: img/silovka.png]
	
	\caption{schéma výkonové části}
\end{figure}

\begin{figure}[h]
	\centering
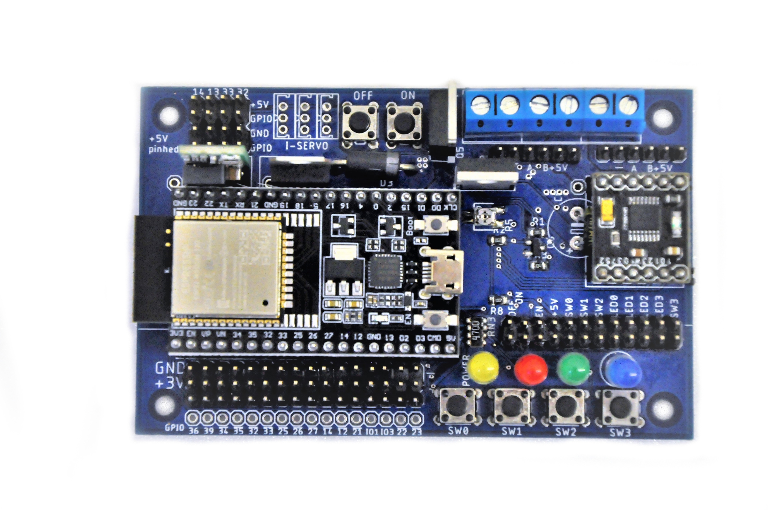
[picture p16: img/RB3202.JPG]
	
	\caption{deska SchoolBoard \label{RB3202_obr}}
\end{figure}

%%%%%%%%%%%%%%%%%%%%%%%%%%%%%%%%%%%%%%%%%%%%%%%%%%%%
\newpage
\renewcommand{\refname}{Literatura}
\printbibliography

\addcontentsline{toc}{section}{Literatura}

\listoffigures
\addcontentsline{toc}{section}{Seznam obrázků}

\listoftables
\addcontentsline{toc}{section}{Seznam tabulek}
\renewcommand{\refname}{Další zdroje}

\begin{thebibliography}{12}
	
	\subsection*{LEGO Mindstorm}	
	\bibitem{lego_cena}
	\textit{porovnání cen LEGa} [online] www.heureka.cz [cit. 2020-02-22] Dostupné z: 
	\url{https://lego.heureka.cz/lego-mindstorms-31313-ev3/#o=2}
	
	\bibitem{lego_obr}
	\textit{porovnání cen LEGa} [online] https://www.google.com/ [cit. 2020-02-22] Dostupné z: \\ 
	\url{https://www.google.com/search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:}
	
	\bibitem{lego}
	\textit{LEGO Mindstorms} [online] https://www.lego.com [cit. 2020-02-22] Dostupné z: \url{https://www.lego.com/en-us/themes/mindstorms/downloads}
	
	\subsection*{Mbot}	
	
	\bibitem{Mbot} 
	\textit{Mbot} [online] https://www.makeblock.com/mbot [cit. 2020-02-22] Dostupné z: \url{https://www.makeblock.com/mbot}
	
	\bibitem{Mbot_obr} 
	\textit{Mbot} [online] https://www.google.com [cit. 2020-02-22] Dostupné z: \url{https://www.google.com/search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:}

	\subsection*{Edison V2.0}
	\bibitem{Edison1} 
	\textit{Meet Edison. Wiltronics | Science and Technology product specialists} [online] https://www.wiltronics.com [cit. 2020-02-22] Dostupné z: \url{https://www.wiltronics.com.au/MeetEdison/}
	
	\bibitem{Edison2}
	\textit{Introducing Edison V2.0 - the newest version of the Edison robot. Edison Programmable Robot - Ideal for school classroom education} [online] https://meetedison.com [cit. 2020-02-22] Dostupné z:
	\url{https://meetedison.com/meet-edison-v2-0/}
	
	\bibitem{Edison_cena}
	\textit{příklad ceny} [online] https://www.robotshop.com [cit. 2020-02-22] Dostupné z: \\ 
	\url{https://www.robotshop.com/ca/en/edison-programmable-v20-robot.html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}
	
	\bibitem{Edison_obr}
	\textit{příklad ceny} [online] https://www.google.com [cit. 2020-02-22] Dostupné z: \\ 
	\url{https://www.google.com/search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:}
	
	\subsection*{OZOBOT}
	\bibitem{OZOBOT1} 
	\textit{OZOBOT} [online] https://www.youtube.com [cit. 2020-02-22] Dostupné z:
	\url{https://www.youtube.com/watch?v=lqR3zDWAQ1o}
	
	\bibitem{OZOBOT2}
	\textit{OZOBOT} [online] https://www.youtube.com [cit. 2020-02-22] Dostupné z:
	\url{https://www.youtube.com/watch?v=Cw30OdlczRo}
	
	\bibitem{OZOBOT_obr}
	\textit{OZOBOT} [online] https://www.google.com [cit. 2020-02-22] Dostupné z:
	\url{https://www.google.com/search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:}
	
	\subsection*{Asuro}
	\bibitem{Asuro_navod} 
	\textit{Asuro} [online] http://www.arexx.com [cit. 2020-02-22] Dostupné z:
	\url{ http://www.arexx.com/downloads/asuro/asuro_manual_en.pdf}
	
	\bibitem{Asuro_cena}
	\textit{Programovatelný robot ASURO ARX-3 USB - Vyhledávání na Heureka.cz. Heureka.cz - Porovnání cen a srovnání produktů z internetových obchodů } [online] https://www.heureka.cz [cit. 2020-02-22] Dostupné z:
	\url{https://www.heureka.cz/?h[fraze]=Programovateln%C3%BD+robot+ASURO+ARX-3+USB}
		
%	\bibitem{Asuro_kurz}
%	\textit{2012 Kurz zakladni robotiky - robot ASURO - talentovaní.cz. Talentovaní.cz - talentovaní.cz} [online] https://vtp.talentovani.cz [cit. 2020-02-22] Dostupné z:
%	\url{https://vtp.talentovani.cz//2012 kurz-zakladni-robotiky-robot-asuro}
	
	\bibitem{Asuro_obr}
	\textit{2012 Kurz zakladni robotiky - robot ASURO - talentovaní.cz. Talentovaní.cz - talentovaní.cz} [online] https://www.google.com [cit. 2020-02-22] Dostupné z:
	\url{https://www.google.com/search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:}
		
	\subsection*{Microbit}
	\bibitem{Microbit1} 
	\textit{Micro:bit Educational Foundation | micro:bit. Micro:bit Educational Foundation | micro:bit} [online] https://microbit.org/ [cit. 2020-02-22] Dostupné z:
	\url{https://microbit.org/}
		
	\bibitem{Microbit2}
	\textit{Cutebot - Micro:bit chytré auto - HW Kitchen. Ochutnejte s námi bastlení! | HWKitchen.cz} [online] https://www.heureka.cz [cit. 2020-02-22] Dostupné z:
	\url{https://www.heureka.cz/?h[fraze]=Programovateln%C3%BD+robot+ASURO+ARX-3+USB}
	
	\bibitem{Microbit3}
	\textit{BBC micro:bit} [online] https://www.hwkitchen.cz [cit. 2020-02-24] Dostupné z:
	\url{https://www.hwkitchen.cz/bbc-microbit-mikropocitac-pro-vyuku-programovani/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}
			
	\bibitem{Microbit_obr1}
	\textit{BBC micro:bit} [online] https://www.google.com [cit. 2020-02-24] Dostupné z:
	\url{https://www.google.com/search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:}
	\bibitem{Microbit_obr2}
	\textit{BBC micro:bit} [online] https://www.google.com [cit. 2020-02-24] Dostupné z:
	\url{https://www.google.com/search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:}
			
			%\subsection*{použité součástky}
			
			\subsection*{součásti desky SchoolBoard}
			
			%\paragraph*{ESP32}
			
			\bibitem{DevKitC}
			\textit{datasheet DevKit C} [online] https://www.espressif.com [cit. 2020-02-22] Dostupné z:
			\url{https://cdn.sos.sk/productdata/05/82/cd413a9e/esp32-devkitc.pdf}
			
			\bibitem{datasheet WROOM}
			\textit{Espressif Systems - Wi-Fi and Bluetooth chipsets and solutions } [online] https://www.espressif.com [cit. 2020-02-22] Dostupné z:
			\url{https://www.espressif.com/sites/default/files/documentation/esp32-wroom-32_datasheet_en.pdf}
			
			\bibitem{ESP32}
			\textit{datasheet ESP32} [online] https://cdn.sparkfun.com [cit. 2020-02-22] Dostupné z:
			\url{https://cdn.sparkfun.com/datasheets/IoT/esp32_datasheet_en.pdf}
			
			\bibitem{ESP32_II} 
			\textit{datasheet ESP32} [online] https://pdf1.alldatasheet.com [cit. 2020-02-22] Dostupné z:
			\url{https://pdf1.alldatasheet.com/datasheet-pdf/view/1148023/ESPRESSIF/ESP32.html}
			
			%\paragraph*{DRV8833 (motorový driver)}
			
			\bibitem{DRV8833}
			\textit{datasheet DRV8833} [online] http://www.ti.com [cit. 2020-02-22] Dostupné z:
			\url{http://www.ti.com/lit/ds/symlink/drv8833.pdf}
			
			%\paragraph*{IRF4905}
			
			\bibitem{IRF4905}
			\textit{datasheet IRF4905} [online] https://www.infineon.com [cit. 2020-02-22] Dostupné z:
			\url{https://www.infineon.com/dgdl/irf4905pbf.pdf?fileId=5546d462533600a4015355e329b1197e}
			
			%\paragraph*{BS170}
			
			\bibitem{BS170}
			\textit{datasheet BS170} [online] https://www.onsemi.com [cit. 2020-02-22] Dostupné z:
			\url{https://www.onsemi.com/pub/Collateral/BS170-D.PDF}
			
			%\paragraph*{7805}
			
			\bibitem{7805}
			\textit{datasheet 7805} [online] https://www.st.com [cit. 2020-02-22] Dostupné z:
			\url{https://www.st.com/resource/en/datasheet/l78.pdf}
			
			%\paragraph*{Step-down}
			
			\bibitem{Step-down}
			\textit{datasheet Step-down} [online] https://arduino-shop.cz [cit. 2020-02-22] Dostupné z:
			\url{https://arduino-shop.cz/docs/produkty/0/698/1502185417.pdf}
			
			%\paragraph*{Mikrospínač}
			
			\bibitem{mikrospinac}
			\textit{datasheet -- mikrospínač} [online] https://www.gme.cz [cit. 2020-02-22] Dostupné z:
			\url{https://www.gme.cz/data/attachments/dsh.630-019.1.pdf}
			
			\subsection*{inteligentní servo LX15D}
			
			\bibitem{inteligentni_servo_LX15D}
			\textit{inteligentní serva LX15D} [online] https://www.google.com [cit. 2020-02-22] Dostupné z:
			\url{https://www.google.com/search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}
			
			\subsection*{Robotický den}
			
			\bibitem{RD2020}
			\textit{Robotický den} [online] http://robotickyden.cz/ [cit. 2020-02-22] Dostupné z:
			\url{http://robotickyden.cz/}
			
		\end{thebibliography}

\end{document}

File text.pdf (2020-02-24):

STREDO ˇ | SKOLSK ˇ | A ODBORN ´ | Á CINNOST ˇ

Obor: 10. Elektrotechnika, elektronika a telekomunikace

# Postav si svého prvního robota

## Tomáš Vavrinec

### Brno 2020

STREDO ˇ | SKOLSK ˇ | A ODBORN ´ | Á CINNOST ˇ
POSTAV SI SVEHO PRVN ´ | ÍHO ROBOTA

### BUILD YOUR FIRST ROBOT

AUTOR | Tomáš Vavrinec
SKOLA | Střední průmyslová škola a Vyšší ˇ
| odborná škola Brno, Sokolská
KRAJ | Jihomoravský
SKOLITEL | Mgr.Miroslav Burda ˇ
OBOR | 10. Elektrotechnika, elektronika a telekomunikace

### Brno 2020

## Prohlášení

Prohlašuji, že svou práci na téma Postav si svého prvního robota jsem vypra-

coval samostatně pod vedením Mgr.Miroslava Burdy a s použitím odborné

literatury a dalších informačních zdrojů, které jsou všechny citovány v práci

a uvedeny v seznamu literatury na konci práce.
Dále prohlašuji, že tištěná i elektronická verze práce SOC jsou shodné ˇ

a nemám závažný důvod proti zpřístupňování této práce v souladu se zákonem č. 121/2000 Sb., o právu autorském, o právech souvisejících s právem au-

torským a změně některých zákonů (autorský zákon) v platném změní.

V Brně dne:

Tomáš Vavrinec

## Poděkování

Děkuji svému školiteli Mgr. Miroslavu Burdovi za obětavou pomoc, podnětné

připomínky a nekonečnou trpělivost, kterou mi během práce poskytoval.

Tato práce byla provedena za finanční podpory Jihomoravského kraje.

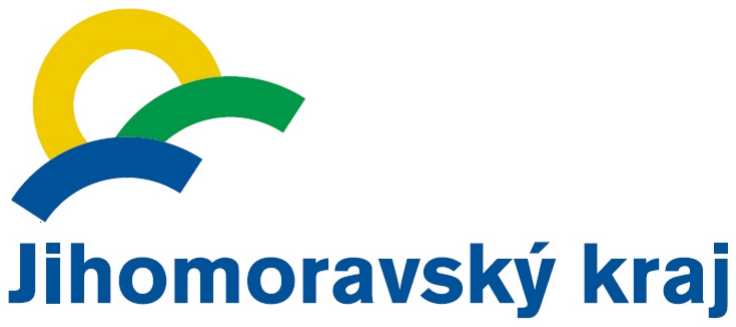
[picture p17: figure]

## Anotace

Cílem práce je vyvinout vhodnou levnou a rozšiřitelnou vzdělávací pomůcku

– řídící desku, která umožňuje názorně předvést vlastnosti senzorů a pohonů

a která bude schopná řídit například i amatérské soutěžní roboty nebo školní

ukázku výrobní linky. Dále vyvinout snadno dostupného robota, kterého tato

řídící deska bude řídit.

Tato práce se zabývá návrhem a výrobou řídící desky Schoolboard a ro-

bota Schoolbot a jejich použitím při výuce dětí v zájmovém vzdělávání a při

školní výuce předmětů elektroniky, automatizace, programování a dalších.

### Klíčová slova

robot; vyuka robotiky; řídící deska; ESP32

## Annotation

### Keywords

# Obsah

Uvod ´ | 8
1 Proč vytvářet vlastní roboty? | 10
2 SchoolBot | 15
3 SchoolBoard | 18

6

Přílohy | 22
A Rídící část ˇ | 23
B Silová část | 29
C Obrazová příloha | 34

7

# Uvod

´

Moje práce má za cíl vytvořit pomůcku (robota) pro praktické seznámení

s elektonikou, robotikou a programováním pro:

- účastníky volnočasových kroužků robotiky, elektroniky a podobných
- studenty středních škol, především oborů elektronika, automatizace,

robotika, ale i pro předměty informatika nebo fyzika

- další začínající zájemce o elektoniku a robotiku.

Pokud zájemce – začátečník o elektroniku a nebo hobby robotiku absol-

vuje ”

blikání ledkou“, obvykle chce pokračovat stavbou svého prvního robota (podle hesla: ”

At’ se to hýbe!“). Když se rozhlédne kudy dál, zjistí, že všechny

dostupné možnosti jsou tak či onak dost problematické (viz kapitola 1.1).

Podobná situace nastává ve škole, kdy například funkci probíraných sen-

zorů, enkodérů a podobně někdy není na čem prakticky ukázat. To se týká

především situace, kdy učitel chce, aby studenti s robotem sami pracovali,

například ve dvojicích.
Rídící deska ˇ | Schoolboard a robot SchoolBot jsou primárně navrženy

pro volnočasový vzdělávací kroužek robotiky pořádaný na naší škole a jsou

určeny pro začátečníky. Jako takoví dávají účastníkům kroužku možnosti,

které má prakticky každý soutěžní robot, konkrétně pohon pro pohyb na

hřišti, klepeta pro manipulaci s herními prvky a senzory pro samostatnou

orientaci na hřišti.

8

Takový robot by měl mít:

- modulární senzoriku – být schopný připojit na sebe různé senzory
- rozšiřitelnou konstrukci – možnost i velké úpravy, změn a rozšíření

konstrukce robota, připojení různých pohonů (motory, serva)

- bezdrátové řízení
- dostatečně tuhou konstrukci
- možnost programovat v C++, které je dnes standardem v této

oblasti

- a hlavně: nízkou pořizovací cenu, protože bez ní jsou všechny ostatní

příznivé vlastnosti bohužel téměř na nic

Ideálně by si takového robota učastníci kroužku měli být schopni postavit, spájet a oživit (podle pokynů vedoucího) sami.

9

# Kapitola 1

# Proč vytvářet vlastní roboty?

Proč vlastně vytvářet vlastní elektroniku i mechaniku, když je na trhu tolik

různých robotu a vozítek? Konkurenční roboti, kteří se běžně prodávají, jsou

totiž většinou velmi drazí a často nemají ani moc možností. Například známé

LEGO Mindstorms, u kterého se cena základní sady pohybuje nad sedmi tisíci korunami [], je vzhledem ke svým možnostem ohromně předražené.

Při vytváření pokročilejších aplikací potřebuje tvůrce znalost technických

specifikací robota a jeho vnitřního fungování. U většiny komerčních robotů

však není kompletní technická dokumentace volně dostupná.

## 1.1 Konkurence

### 1.1.1 LEGO Mindstorms EV3

LEGO Mindstorms je známé svou jednoduchostí. Základní roboti se s touto

sadou dají sestavit velmi rychle, což poskytuje hlavně začátečníkům motivaci, nebot’ již s poměrně malým úsilím sestaví něco, co na první pohled

funguje. Dílky LEGa však nejsou moc pevné a konstrukce z nich postavená

jich tedy vyžaduje velké množství, aby byla obstojně tuhá. To se samozřejmě

dá vyřešit tím, že si člověk udělá konstrukci z jiného materiálu, potom ale

odpadá výhoda jednoduchosti stavby.

Možnosti robota se z velké části odvíjí od senzoriky. LEGO trpí na ne-

10 dostatek senzorů. Nejen, že v základní sadě je, krom tlačítka, od každého

sensoru jen jeden kus. Ale ani kostka, řídící centrum LEGa, nedokáže číst víc

než čtyři senzory naráz. Je pravda že LEGO má možnost spojovat několik

kostek dohromady, to však samozřejmě vyžaduje mít jich víc, což je při ceně

LEGa poměrně drahé.

LEGO má své vlastní programovací prostředí, které je většinou pro začátečníky

dobré. Jakmile však uživatel chce vytvářet vetší program, prostředí velmi

rychle ztratí užitečnost. Vetší programy jsou v grafickém prostředí velmi

nepřehledné. Navíc prostředí LEGa může být u větších programů nesta-

bilní. Existují však i prostředí, ze kterých se dá lego programovat textově,

například v jazyku C++, což je u složitějších programu přehlednější a také

méně náročné pro počítač.

### 1.1.2 Mbot

Mbot je oproti legu daleko levnější (cena se pohybuje kolem osmnácti set

korun za kus) ale trpí stejným, nebo i větším, nedostatkem sensorů.

Co se konstrukce týče, problémy s pevností u Mbota není, ale zase se

nedá snadno upravit. Konstrukce je totiž hliníková, což je v pořádku, pokud

není potřeba konstrukci výrazně upravovat. Robota je ale většinou třeba

přizpůsobit konkrétnímu užití. Ze zkušenosti se nejvíce osvědčilo dřevo, které

se dá jednoduše upravovat bez větší námahy a zároveň není problém z něj

udělat dostatečně tuhou konstrukci. Hliník se však tak lehce ručně upravovat

nedá.

Mbot je založen na procesoru ATmega328, což je stejný procesor, jaký

se používá i u velice známého Arduina. To znamená, že některé programy,

které jsou napsané pro Arduino, je možné spustit i zde.

### 1.1.3 Edison V2.0

Edison je velmi podobný LEGu a má i podobné problémy. Opět nedisponuje

velkým počtem senzorů, ale oproti LEGu je alespoň daleko levnější.

11

Stejně jako LEGO má i Edison vlastní grafické programovací prostředí,

bohužel jsem jej nikdy nepoužíval, ale vypadá velmi podobně jako prostředí

LEGa. Myslím si proto, že stejně jako prostředí LEGa bude i toto velice

dobré na malé prográmky pro děti, ale nevhodné pro obsáhlé programy.

Všechny senzory má Edison uvnitř sebe a nedají se proto dovést na místo,

kde je uživatel nejvíc potřebuje. Uživatel se proto musí přizpůsobit rozložení

senzorů na řídící jednotce, stejně tak se nedá vyvést ani nic jiného. Jediné, co se dá, je vyměňovat kola (například za nějaké ozubení) a pomocí toho si

pak dovést náhon z motoru na potřebné místo.

### 1.1.4 Mbot

Mbot je oproti legu daleko levnější (cena se pohybuje kolem osmnácti set ko-

run za kus) ale trpí stejným, nebo i větším, nedostatkem sensoru. Co se kon-

strukce týče, problémy s pevností u Mbota není ale zase se nedá snadno upra-

vit. Konstrukce je totiž hliníková, což je v pořádku, pokud není potřeba kon-

strukci výrazně upravovat. Robota je ale většinou třeba přizpůsobit konkrétnímu

užití, ze zkušenosti se nejvíce osvědčilo dřevo, které se dá jednoduše upravo-

vat bez větší námahy a zároveň není problém z něj udělat dostatečně tuhou

konstrukci. Hliník se však tak lehce ručně upravovat nedá. Mbot je založen

na procesoru ATmega328 což je stejný procesor jaký se používá i u velice

známého arduina. To znamená že některé programy, které jsou napsané pro

arduino je možné spustit i zde.

### 1.1.5 Edison V2.0

Edison je velmi podobný legu a mí i podobné problémy. Opět nedisponuje

velkým počtem senzoru ale oproti legu je daleko levnější. Stejně jako lego

má i Edison vlastní grafické programovací prostředí, bohužel jsem jej nikdy

nepoužíval, ale vypadá velmi podobně jako prostředí lega. Myslím si proto, že

stejně jako prostředí lega bude i toto velice dobré na malé prográmky pro děti,

ale nevhodné pro obsáhlé programy. Všechny senzory má Edison uvnitř sebe

12 a nedají se proto dovést na místo kde je uživatel nejvíc potřebuje. Uživatel

se proto musí přizpůsobit rozložení senzoru na řídící jednotce, stejně tak se nedá vyvést ani nic jiného. Jediné, co se dá, je vyměňovat kola (například za

nějaké ozubení) a pomocí toho si pak dovést náhon z motoru na potřebné

místo.

### 1.1.6 OZOBOT

Ozobot je mini robot, z toho vyplývají jeho největší výhody i nevýhody.

Například pochopitelně není dělaný na to, aby cokoli vozil nebo jakkoliv

stěhoval. Téměř se nedá upravovat, na to ale opět není dělaný. Jeho účel

je především jezdit po čáře a vykonávat příkazy na ní zapsané pomocí ba-

revných vzorů. Přes to že se novější verze dají i programovat, jejich funkce

jsou pořád mířené do velké míry právě na čáru a barevné příkazy na ní.

### 1.1.7 Asuro

Asuro je robot postavený kolem základní desky. Jedná se o stavebnici, ale

přesto nemá ani jednoduché pomůcky pro možnost přesné stavby. Asuro má

mezi koly a motorem převodovku, která se ukládá do jakýchsi ložisek. Ta

se bez jakéhokoli zapozicování napájí na plochu desky. Výsledkem je téměř

nemožnost uložit kola převodovky přesně.

### 1.1.8 Microbit

Microbit je především řídící deska se senzory a výstupními ledkami. Není to

primárně vozítko, přestože existují konstrukce, které jsou určené právě pro

řízení microbitem. Taková konstrukce však muže využívat pouze serva, nebo

musí mít vlastní řízení motoru. Microbit totiž motory řídit nedokáže sám,

dokáže řídit jen serva, která si řízení řeší sama. Toto však není velký problém,

protože existuje více různých konstrukcí, které právě toto řeší.

Microbit má překvapivě docela dost senzorů přímo na základní destičce.

Podle mých informací kompas, který je přímo na desce téměř nefunguje, ale

13 vzhledem k tomu, co všechno na sobě malá destička Microbit má, to není až

taková tragédie. Kompas je stejně často potřebné dostat co nejdál od zbytku

robota, kvůli všemožnému rušení, takže by se i tak dost možná používal jako

externí součástka.

Microbit má zároveň matici ledek, na které si uživatel muže zobrazova,t

co se mu zlíbí a zároveň se jimi dá i měřit světelnost okolí. Používání led diod

jako fotodiod sice není tak přesné, nicméně to jde a je to zajímavé řešení.

### 1.1.9 Shrnutí

Komerční systémy jsou většinou velmi drahé, mívají nedostatek senzorů,

mívají měkkou nebo obtížně upravitelnou konstrukci a také nemají moc velký

výkon ani přesnost pohonu.

Možná si říkáte, proč mi záleží na tom aby robot pro začátečníky měl všechny tyto možnosti. Vždyt’ člověku, co nikdy robota nestavěl, by to mohlo

být skoro jedno. Ano, ale já chci, aby se na prvním robotu, které si zájemce

postaví, dalo stavět dál. Aby bylo vidět, že si z robota, který toho moc

neuměl, může uživatel postavit něco, co by třeba mohlo jezdit na soutěže a

vyhrávat.

robot | modulární senzorika | rozšiři-telnost | bezdrátové řízení | tuhá konstrukce | nízká cena | C++¹
Mbot LEGO² Edison OZOBOT Asuro Microbit SchoolBot | 0 1/2 0 0 0 0 1 | 0 1 0 0 0 1 1 | 0 1 1/2 1 0 1 1 | 1 0 1/2 1 0 1 1 | 0 0 1 0 0 0 1 | 0 1/2 0 0 1 0 1

Tabulka 1.1: Srovnání možností dostupných komerčních systémů pro hobby

roboty

14

# Kapitola 2

# SchoolBot

## 2.1 Z čeho se SchoolBot skládá?

SchoolBot je komplet, skládající se ze řady jednotlivých dílků, které nebudu

popisovat samostatně pro začátek systém rozdělím na elektroniky a mecha-

niku.

### 2.1.1 Elektronika

Elektronika je především řídící deska SchoolBoard kterou shrnuji v samo-

statné kapitole a detailně rozebírám v přílohách. Krom desky obsahuje SchoolBot battery pack, motory s enkodéry a inteligentní serva LX15D[viz zdroje]

které uvádí do provozu klepeta, nástroj pro možnost manipulace s objekty

při soutěžích především herními prvky.

battery pack

Battery pack je sestaven ze dvou li-on baterii 18650 které jsou pomocí DPS

spojeny v jeden celek. Připojení do robota je pak zajištováno pomocí dutinek a to každý článek zvlášt’, serializují se až po vložení do robota. Důvodem

pro vyvádění obou článku zvlášt’ je nabíjení, to je totiž realizováno pomocí

lineárních nabíjecích modulu, které se napájejí z USB a každý článek se nabíjí

15 zvlášt’. Aby se battery pack nedal omylem připojit s opačnou polaritou je

vyřešen tak že se dá při připojení otočit dvěma způsoby a oba mají správnou

polaritu, dokonce i stejné pořadí článků.

motory s enkodéry

SchoolBot používá levné motory s plastovou převodovkou které v základu en-

kodéry nemají. Enkodéry si proto SchoolBot řeší sám, a to pomocí magnetu

a dvou halových sond. Takto vyrobený inkrementální enkodér pak vyhodno-

cuje procesor na řídící desce.

### 2.1.2 Mechanika

Mechanika SchoolBota je celá z překližky vypálené pomocí laserového řezáku.

Je stavěná kruhově aby se robot nemohl zaseknout v nějakém rohu a v přední

části má umístěná klepeta kterými je schopna nabírat a převážet různé ob-

jekty.

Uložení kol a motoru

Kola nejsou jen tak nasazená na motor. Aby se nevyvracela, a tím pádem

méně zatěžovala převodovku motoru, jsou z druhé strany podepřena a uchy-

cena k obvodu konstrukce. Celí motor i s kolem je pak z části držen podporou

kola ale především je celí motor vložen do těsné šachty kde se nemůže otočit

ani posunout jiným směrem než vzhůru a následně je přitlačen palubou která

se přišroubuje čtyřmi šrouby. Takovéto řešení umožnuje jednoduchý přístup

k motoru.

16

Klepeta

Klepeta jsou postavena tak aby měla osu otáčení, co nejdále od sebe. Protože

aby robot ve chvíli kdy s otevřenými klepety narazí do mantinelu musí mít

konce klepet k sobě blíž než osy jejich otáčení aby se klepeta sama zavřela (o mantinel bez potřeby řízení). Z tohoto důvodu jsou serva, na kterých jsou

klepeta uložena, posazena co nejdál od sebe, právě aby se klepeta mohla “

bezpečně“ otevřít co nejvíc.

17

# Kapitola 3

# SchoolBoard

## 3.1 Popis desky

Deska má k dispozici

- třicetidvoubitový procesor ESP32 s taktovací frekvencí 240 MHz a

napájecím napětím 3,3 V

- flash pamětí 4 MB (dělají se i verze s 8 a 16 MB), 520 KB SRAM,

WI-Fi, Bluetooth, 28 vstupně výstupních piny, dva ADC převodníky (jeden s 6 piny a druhý s 10 piny), jedním DAC převodníkem s dvěma

piny, tři UARTy, dvě SPI, tři I2C(jedno je použito interně pro flash)

atd.

- Motorový driver DRV8833, který umožnuje řídit dva stejnosměrné mo-

tory nebo jeden krokový motor.

- Tři konektory na inteligentní serva LX-15D nebo LX-16A. Deska dokáže

řídit až 254 těchto serv. Serva se totiž dokáží řetězit za sebe, ale pokud potřebují větší proud (když podávají větší kroutící moment), ubytek

napětí na kabelech je už moc velký, aby serva mohla využít plný výkon.

Proto jsou na desce konektory tři a ne jen jeden.

- Ctyři uživatelská tlačítka. ˇ

18

- Tři uživatelské LED a jedna LED signalizující zapnutý stav.
- Možnost měření napětí baterie.
- Hardwarové řešení startu a vypínání (dá se použít i jako nouzový

vypínač). Tlačítka na zapínání a vypínání jsou jak přímo na desce, tak

jsou i vyvedena na pinheady pro možnost připojení externího řízení.

- Konektor na připojení motorů s enkodérem.
- Deska operuje na napětí 3,3 V, ale aby byla schopná komunikovat

i s periferiemi operujícími na napětí 5 V, jsou čtyři piny opatřené převodníkem napět’ových úrovní. Piny IO35, IO32, IO14 a IO12 jsou

tedy schopny operovat jak na napětí 3,3 V, tak na 5 V.

Piny jsou teoreticky schopné pracovat i na napětí vyšším, záleží na součástce IM3 (step-down nebo stabilizátor 7805), která napájí převodník.

Pokud bude IM3 dodávat jiné napětí, bude toto napětí i na 5 V pinech (napětí nesmí klesnout pod 4,5 V jinak procesor nedostane dost

proudu).

- Vyvedení 5 V napájení je na oddělené stabilizaci (součástka IM4) pro

možnost napájení jiným napětím.

- Deska má také vyvedeny všechny piny ESP32, které nejsou spojeny s

hlavní funkcí desky (řízení motorů) a není problematické se o ně starat

při bootu ESP32.

### 3.1.1 Možné periferie

Vzhledem k tomu že je deska řízena procesorem ESP32, který umožnuje

komunikaci po řadě sběrnic a disponuje i svým vlastním AD převodníkem (přesto že ne úplně perfektním). Je schopna pracovat s velmi rozsáhlou řadou periferii. Díky převodníku napět’ových úrovní navíc umožnuje komunikaci

ne jen na 3.3V (pracovní napětí procesoru) ale i na napětí 5V (při jiném

nastavení jisté součástky[viz přílohy] i jiném napětí vyšším než 3.3V).

19

Příklady možných senzoru

- Kamera
- Ultrazvukoví dálkoměr
- Infračervený dálkoměr
- Laseroví dálkoměr
- Senzory na sledování čáry
- Senzory barev
- Gyroskop
- Akcelerometr
- Kompas
- Hodiny reálného času
- Teplotoměr
- Barometr
- Senzor osvětlení
- Vlhkoměr
- A mnoho dalších

Příklady jiných periferii

- Inteligentní serva (např. LX15D nebo LX16A)
- Inteligentní ledky (např. WS2812)
- Modelářská serva

20

- Stejnosměrné motory (s rozsahem napětí od 6 do 11V a proudem do

1A [při použití silnější verze stejného driver do 1,5A])

- Krokoví motor
- Obyčejné ledky
- Elektromagnetické ventily

## 3.2 Vývoj

SchoolBot jsem začal vyvíjet, protože účastníci kurzu robotiky v minulých

letech nestíhali za jeden školní rok vytvořit vlastní konstrukci a ještě ji na-

programovat. Přesto, že elektroniku již vyřešenou měli, tak mechanika a

především programování na ně bylo stále příliš. Přitom robotické soutěže jsou

”

zlatým hřebem“ každého školního roku. Proto jsem začal koncem loňského školního roku 2018/2019, vyvíjet robota, který měl řešit jak elektroniku, tak

většinu mechaniky.

První prototyp mechaniky byl hotový již začátkem letních prázdnin, ale

další vývoj pokračoval až o hodně později. První verze totiž vyžadovala jen

velmi málo úprav a já měl na práci spoustu jiných věcí. V první řadě řídící

desku, která již sice také měla první prototyp za sebou, ale vyžadovala da-

leko víc úprav. Již druhá verze desky byla plně provozuschopná a začátkem školního roku 2019/2020 jsme jí začali stavět s účastníky kurzu.

Ne všichni však chtěli použít mojí konstrukci. Někteří si jí chtěli navrh-

nout sami a někteří měli tak těžké doplňky, že by je tento robot neuvezl.

SchoolBota tak letos využil jen jeden ze sedmi týmů.

## 3.3 Kde se deska používá

Deska se používá ve dvou volnočasových kurzech robotiky a při výuce elek-

trotechniky a automatizace.

21

# Závěr

22

# Příloha A

# Rídící část ˇ

## A.1 DEVKIT C:

procesor ESP32 je v tomto případě osazený na devkitu C. Je to malá deska, která se stará o potřeby procesoru a dá se koupit jako celek. Zajišt’uje jedno-

duché programování přes USB, zajištuje stabilizované napětí 3,3V pro ESP32

a 3,3V větev na desce a stará se o výchozí hodnoty na pinech u kterých je to

potřeba. Seznam důležitých pinů

- EN – reset pin, pokud je na něm logická 0, ESP32 se resetuje, v

normálním stavu na něm má být logická 1, proto je zde pull-up re-

zistor, který zajištuje logickou 1.

- Piny s označením reserv AD1 jsou vyhrazené pro externí použití a

nejsou tedy na desce nijak zapojené, jsou to piny, na které je připojený první AD převodník ESP32 (ADC1), ADC1 je plně k užití pro uživatele

na rozdíl od ADC2, který je využíván Wi-Fi. ADC2 je tedy uživateli k

dispozici, jen pokud jej zrovna nevyžaduje Wi-Fi.

- Piny s označením AD1 jsou také piny ADC1, ale jsou interně připojené

na některé periferie, která však nemusí být použité

•

23

- IO34 – použitelná na měření napětí na baterii přes jumper JP2 přímo

na desce

•

- IO35 – pin řídící inteligentní serva

•

- IO33, 32 jsou připojené na převodník napět’ových úrovní pro možnost

komunikovat na 5V. Analogové měření je ovlivněno pull-up rezistory na převodníku napět’ových úrovní. Při potřebě užití těchto pinů jako

analogových vstupů tedy doporučuji odebrat tyto pull-up rezistory. To

znamená, že tyto piny budou potřebovat softwarové pull-upy při užití

jako vstupní pin při 5V komunikace.

- Piny s rudým označením THIS SIGNAL MUST BE HERE, jsou lehce

problematické, protože ovlivňují boot ESP. Musí na nich tedy při bootu

být správná logická hodnota, jinak by ESP mohlo třeba bootovat z jiné

paměti nebo by třeba USB nemohlo zapisovat do paměti pro program.

Piny IO0 a IO2 nejsou vyvedeny a je o ně interně postaráno, pin IO12

je ale vyveden a uživatel si tedy musí dát pozor, aby na něm neměl při

bootu logickou 1. Pokud zůstane nepřipojen, deska se o něj postará.

A.1.1 D2

Dioda sloužící k zamezení napájení 5V větve z USB. Ochrana před

přetížením napájení z USB.

### A.1.2 RN3A, B, C, D:

rezistorová sít’, odpory k ledkám.

24

### RN2A, B, C, D:

rezistorová sít’, ochranné odpory ke tlačítkům, aby byl procesor chráněn

při případné chybě v programu.

SW0, 1, 2, 3:

uživatelská tlačítka

C3, 4, 5, 8:

kondenzátory pro vyhlazení signálu z tlačítka při stisknutí

JP4, 9:

vyvedení tlačítek a ledek ven z desky pro možnost vyvedení dál od

desky, např. deska muže být v útrobách robota, ale tlačítka a ledky

mohou být pořád pohodlně dostupné, protože jsou vyvedené někam na

povrch stroje.

### LED0, 1, 2:

ledky pro možnost signalizace různých stavů programu

### Led3:

powerled, signalizace, zda je deska zapnutá nebo vypnutá

JP6, 12:

konektor pro připojení motoru s encoderem

25

- Vnější piny – napájení motoru
- Piny vedle vnějších pinů – napájení encoderu
- Vnitřní piny – signály encoderu
- Konektor je primárně určen pro inkrementální magnetické encodery, s

nimi i počítají programové knihovny

JP5:

vyvod 3.3V napájení

JP8, 11:

vyvedení některých pinů ESP, každý pin je vyveden alespoň dvakrát pro

možnost připojení osciloskopu pro příjemnější hledání chyb programu.

### LEVEL SHIFTER:

Neboli převodník napět’ových úrovní zajištuje možnost digitální komu-

nikace s 5V periferií pro čtyři piny ESP. Konkrétně pro piny IO32,

IO33, IO14, IO12.

- IO32 – jeden z pinů ADC1, podrobněji u DEVKIT C.
- IO33 – jeden z pinů ADC1, podrobněji u DEVKIT C.
- IO14 – jeden z pinů ADC2. ADC2 je využíván Wi-Fi. Jinak není použit.
- IO12 – je nutno odstranit pull-up (na součástce převodníku). IO12 volí pamět’, ze které se bootuje a jestli do té správné jde nahrát program.

Jinak není interně použit.

- Všechny čtyři piny jsou jinak vyvedeny i ve variantě 3.3V.

26

- Převodník napět’ových úrovní převádí logickou 1 pomocí pull-upů, tím

pádem periferie pomocí převodníku spojené musí mít vstup s vysokým

odporem, protože pokud by piny těchto periferií neměly velký odpor,

tak by výsledek po dělení děliče vzniklého z pull-upu a periferie, která

signál měří, mohl být pod rozlišovací schopností dané periferie.

JP1, 3, 7:

vývody zpětivoltovaných pinu a jejich napájení

- Napájení 5V nemusí být nutně 5V, tyto piny mají vlastní stabilizaci

napájení (IM3), a tím pádem záleží na tom, jak je tato stabilizace

nastavená. Deska je primárně navržená pro dva způsoby stabilizace:

step-Down a stabilizátor řady 7805

•

- Step-Down má výhodu většího proudu, a hlavně nastavitelného napětí

na výstupu. Naopak nevýhoda je nutnost nastavit požadované napětí

a konkrétně u mnou používaného exempláře poměrně velký rozkmit

výstupního napětí při změně odběru proudu.

•

- 7805 má výhodu napět’ové stability naopak nevýhodu maximálního

možného odebíraného proudu který závisí na vstupním napětí. Co se

regulace napětí týče, v mnou použitém zapojení se napětí regulovat

nedá.

R5:

Trimr sloužící jako dělič napětí baterie pro možnost měření jejího napětí.

Před použitím nutno nastavit na vhodnou dělící hodnotu vzhle-

dem k použitým bateriím! Na výstupu z děliče nesmí být při plně

27 nabité baterii víc než 3,6V. Pokud se při daném použití desky nemá měnit maximální napětí na baterii (počet článků baterie nebo jejich

druh), doporučuji nastavit trimr jednou a následně jej zalepit, aby se

například vibracemi nemohl rozladit.

JP2:

jumper pro možnost odpojení měření baterie za účelem uvolnění ana-

logového pinu IO34. Zároveň se dá použít na měření výstupu z děliče

před jeho zapojením k ESP.

28

# Příloha B

# Silová část

### B.0.1 Power manager:

X4: Svorkovnice pro připojení zdroje s napětím 7-11V. X4-1 je záporný

pól a X4-2 je pól kladný.

Q5 MOSFET tranzistor typu P na ochranu proti přepólování

Můžete si všimnout, že ochranná dioda uvnitř tranzistoru směřuje po

směru proudu, a ne proti směru, což by bylo normální zapojení MOS-

FET tranzistoru. Tranzistor je zapojen takto právě z toho důvodu, že

slouží jako ochrana proti náhodnému přepólování zdroje. Kdyby byl

naopak, tak by sice při správné polaritě zdroje proud propustil a deska by byla napájena, ale v případě přepólování by proud propustil (skrz

diodu) také, sice s ubytkem napětí na diodě, ale přes to by proud prošel

a spálil by vše, co je citlivé na změnu polarity.

Q2 MOSFET tranzistor typu P, který umožnuje zapínání a vypínání

desky

R3 Pull-up na bateriové napětí pro dráhu START GATE1

29

Q6 MOSFET tranzistor typu N řídící tranzistor Q2

R2 Pull-up na 3.3V pro dráhu OFF

- V zapnutém stavu drží na dráze OFF 3.3V (ne úplně čisté napětí ze

stabilizátoru na ESP kvůli pull-downu R1) a tím otvírá tranzistor Q6,

který zas drží otevřený tranzistor Q2.

R1 Pull-down pro dráhu OFF

- Tento rezistor je zde pro plné definování dráhy OFF, a to i ve stavu,

kdy ESP není zapojeno, tím pádem by dráha nebyla jasně určena.

SW5 Tlačítko, které připíná dráhu OFF k zemi, a tím zavírá tran-

zistor Q6, čímž vypíná desku.

SW1 Tlačítko připínající dráhu ON k zemi, čímž skrz kondenzátor

C1 a tranzistor Q2 zapne stabilizátor na DEVKIT-C, který pomocí

rezistoru R2 otevře tranzistor Q6, který otevře Q2.

C1 Kondenzátor, který se nabije při stisku tlačítka SW4, čímž na

dobu nabíjení přivede na dráhu START GATE zem a tím krátkodobě

otevře tranzistor Q2. Přes Q2 projde proud, který pomocí stabilizátoru

na DEVKIT-C vytvoří 3,3V, skrz pul-up R2 otevře tranzistor Q6 a ten

trvale otevře tranzistor G2.Deska je v tu chvíli zapnutá.

R4 Rezistor pro vybíjení kondenzátoru C1

JP6 Konektor, pro možnost vyvedení vypínaní, zapínání, resetu a

kontrolní powerledky na externí ovládání.

30

Obvod jako celek Po připojení zdroje s napětím mezi 7 až 11V se

při špatné polaritě napětí nedostane skrz tranzistor Q5. Deska sice ne-

jede, protože nemá napájení, ale je chráněna před zničením opačnou

polaritou. Při správném připojení zdroje, napětí projde skrz Q5 a tím

pádem je na drahách BAT POL+, START GATE1 a ON napětí zdroje,

na VCC se napětí nedostane, protože tranzistor Q2 je zavřen. Při stisku

tlačítka SW4 se na dráhu ON dostane zem, tím pádem se kondenzátor

C1 nabije a při nabíjení krátkodobě otevře tranzistor Q2. V době, kdy

je tranzistor Q2 otevřen, skrz kondenzátor C1, se pomocí stabilizátoru

osazeném na DEVKITu-C vytvoří napětí 3.3V. Skrz pul-up R2 se do-

stanou 3.3V na dráhu OFF a tím pádem na Gate tranzistoru Q6, který

se v tu chvíli otevře a trvale přivede zem na dráhu START GATE1. V

tuto chvíle je tranzistor Q2 trvale otevřen, až do doby, kdy se na dráhu

OFF nepřivede zem, v tu chvíli se zavře tranzistor Q6 protože má na Gate stejné napětí jako na Source (oba piny je připojené k zem). Po-

kud je Q6 zavřený zbývá jen možnost připojení země odjinud, pokud

uvažujeme tento obvod bez poškození nebo jakéhokoli doplnění. Skrz

rezistor R3 je dráha START GATE1 připojena na zdrojové napětí, tím

pádem je tato dráha tahána ke kladnému pólu a na k pólu zápornému,

což by bylo potřeba pro otevření tranzistoru Q2, tímto způsobem se

tedy Q2 určitě neotevře. START GATE1 je dále připojen na rezistor

R4 a kondenzátor C1 které jsou dále připojeny na přes tlačítko SW4

k zemi. Pokut je tedy tlačítko SW4 spojeno se zemí je zem i na dráze

ON, v tuto chvíli je sice na dráhu STERT GATE1 skrz R4 připojena

zem, ale vzhledem k tomu že R4 má desetkrát větší odpor než R3, který

spojuje dráhu START GATE s bateriovým napětím, na Gate tranzis-

toru Q2 pořád nebude dostatečně malé napětí, aby se Q2 otevřel. C1

propustí proud jen po dobu jeho nabíjeni a tím pádem se skrz nej nedá

deska udržet trvale otevřená, dá se jím jen zapnout. To znamená že

pokud procesor napíše na pin připojený na dráhu OFF, IO13, logic-

kou nulu, deska se vypne, bez ohledu na to, jaké tlačítko člověk drží.

31

Vypínání ne nutně platí pro 3.3V větev která je napájena jak z baterie

tak z micro-USB na DEVKITu-C, takže pokud je procesor připojen

k počítači pravděpodobně za účelem programování procesor a vše co

je napájené z 3.3V je nadále funkční. Pokud USB není zapojeno, pak

se při stisku SW5 nebo zápisu logické 0 na pin IO13 deska jednoduše

kompletně vypne.

IM10

Motorový driver, DRV8833, na řízení dvou stejnosměrných motorů v napět’ovém rozsahu 2,7 až 11V a maximálním proudem 1,5A. Driver je

také schopný místo dvou stejnosměrných motorů řídit jeden krokový motor. DRV8833 má pět vstupních řídících pinů: čtyři IN piny (dva pro

každý motor) a sleep pin. Podle IN pinů se řídí výstup - viz tabulka.

Sleep pin uvádí driver do sleep módu pokud je připojen k zemi. Sleep

mód slouží uživateli k úspoře energie v době, kdy nepotřebuje ovládat motory (po dobu aktivního sleep modu zůstanou motory pochopitelně

vypnuté).

xIN1 | xIN2 | xOUT1 | xOUT2 | FUNCTION
0 0 1 1 | 0 1 0 1 | Z L H L | Z H L L | Coast/fast decay Reverse Forward Brake/slow decay

Tabulka B.1

32

X1, X2

Svorkovnice na silové vývody k motorům.

IM3

Step-down/stabilizátor pro 5V větev

- 5V napájí ESP, tím pádem i celou 3.3V větev skrz DEVKIT C
- Napětí, které je, zde je zároveň i napětí, na kterém komunikují 5V piny,

proto doporučuji sem dát stabilizátor 7805, u kterého nemusíte hlídat

napětí.

IM4

Step-down/stabilizátor pro napájení 5V pinů na 5V piništi.

JP42, 47, 48

Konektory pro připojení inteligentních serv.

- Navrženo pro serva LX-16A a LX-15D

C6

Velký elektrolytický kondenzátor jako zásobárna proudu při náhlé změně

odběru.

D3

Zpětná dioda pro případ napět’ové špičky, která by krátkodobě převrátila

polaritu. V takovém případě se dioda otevře a proud propustí skrz sebe

místo, aby protekl jinudy a přitom něco zničil.

33

# Příloha C

# Obrazová příloha

34

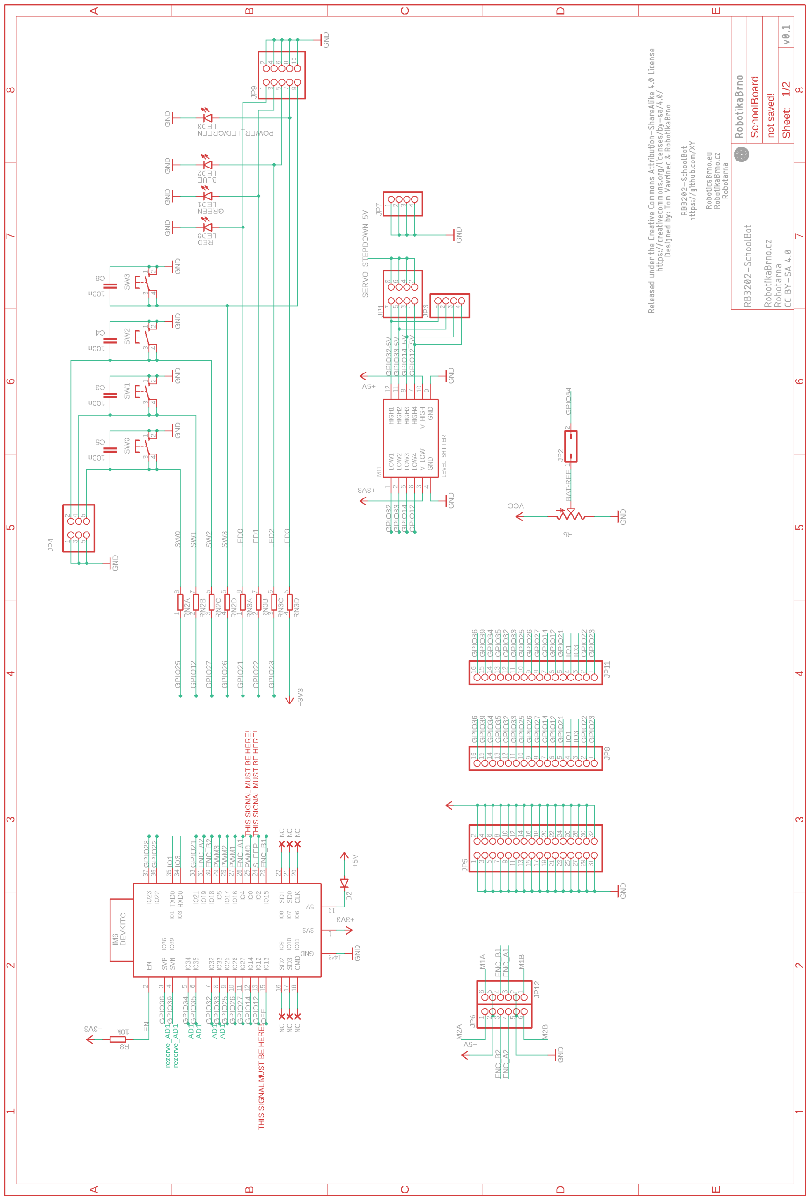
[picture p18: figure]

Obrázek C.1: schéma logické části desky 35

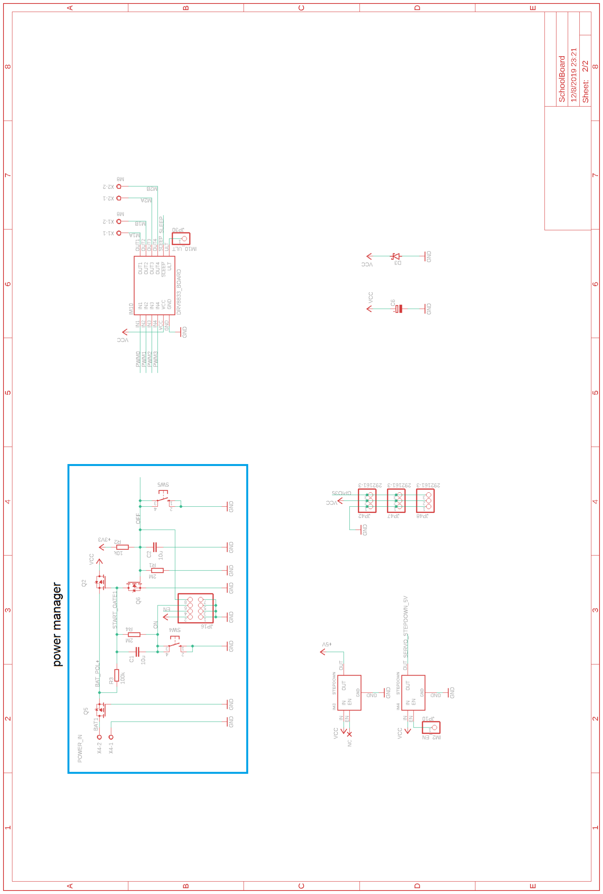
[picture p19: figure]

Obrázek C.2: schéma výkonové části 36

# Seznam obrázků

C.1 schéma logické části desky | 35
C.2 schéma výkonové části | 36

37

# Seznam tabulek

1.1 Srovnání možností dostupných komerčních systémů pro hobby

38

# Bibliografie

### LEGO Mindstorm

[1] porovnání cen LEGa [online] www.heureka.cz [cit. 2020-02-22] Dostupné

z:

https://lego.heureka.cz/lego-mindstorms-31313-ev3/#o=2

### Mbot

[2] Mbot [online] https://www.makeblock.com/mbot [cit. 2020-02-22] Do-

stupné z: https://www.makeblock.com/mbot

### Edison V2.0

[3] Meet Edison. Wiltronics — Science and Technology product specialists

[online] [cit. 2020-02-22] Dostupné z: https://www.wiltronics.com.au/

MeetEdison/ (https://www.wiltronics.com.au/MeetEdison/)

[4] Introducing Edison V2.0 - the newest version of the Edison ro-

bot. Edison Programmable Robot - Ideal for school classroom education [online] [cit. 2020-02-22] Dostupné z: https://meetedison.com/

meet-edison-v2-0/ (https://meetedison.com/meet-edison-v2-0/)

[5] příklad ceny [online] [cit. 2020-02-22] Dostupné z:

https://www.robotshop.com/ca/en/edison-programmable-v20-robot.

39 (https://www.robotshop.com/ca/en/edison-programmable-v20-robot.html)

html?gclid=Cj0KCQiA4sjyBRC5ARIsAEHsELHtKqVNJOl95kMUC8iBngIkgc3gCZU9KOTwuXWEo4hU4Qs1B-2wASkaAh9CEALw_

wcB (https://www.robotshop.com/ca/en/edison-programmable-v20-robot.html)

### OZOBOT

[6] OZOBOT [online] [cit. 2020-02-22] Dostupné z: https://www.youtube.

com/watch?v=lqR3zDWAQ1o (https://www.youtube.com/watch?v=lqR3zDWAQ1o)

[7] OZOBOT [online] [cit. 2020-02-22] Dostupné z: https://www.youtube.

com/watch?v=Cw30OdlczRo (https://www.youtube.com/watch?v=Cw30OdlczRo)

### Asuro

[8] Asuro [online] [cit. 2020-02-22] Dostupné z: http://www.arexx.com/

downloads/asuro/asuro_manual_en.pdf (http://www.arexx.com/downloads/asuro/asuro_manual_en.pdf)

[9] Programovatelný robot ASURO ARX-3 USB - Vyhledávání na Heu-

reka.cz. Heureka.cz - Porovnání cen a srovnání produktů z internetových obchodů [online] [cit. 2020-02-22] Dostupné z: https://www.heureka.

cz/?h[fraze]=Programovateln%C3%BD+robot+ASURO+ARX-3+USB (https://www.heureka.cz/?h[fraze]=Programovateln%C3%BD+robot+ASURO+ARX-3+USB)

[10] 2012 Kurz zakladni robotiky - robot ASURO - talentovaní.cz. Talento-

vaní.cz - talentovaní.cz [online] [cit. 2020-02-22] Dostupné z: https://

vtp.talentovani.cz//2012kurz-zakladni-robotiky-robot-asuro

### Microbit

[11] Micro:bit Educational Foundation — micro:bit. Micro:bit Educational

Foundation — micro:bit [online] [cit. 2020-02-22] Dostupné z: https:

//microbit.org/

40

[12] Cutebot - Micro:bit chytré auto - HW Kitchen. Ochutnejte s

námi bastlení! — HWKitchen.cz [online] [cit. 2020-02-22] Do-

stupné z: https://www.heureka.cz/?h[fraze]=Programovateln%C3%

BD+robot+ASURO+ARX-3+USB (https://www.heureka.cz/?h[fraze]=Programovateln%C3%BD+robot+ASURO+ARX-3+USB)

### součásti desky SchoolBoard

[13] Espressif Systems - Wi-Fi and Bluetooth chipsets and solutions [on-

line] [cit. 2020-02-22] Dostupné z: https://www.espressif.com/sites/

default/files/documentation/esp32-wroom-32_datasheet_en.pdf (https://www.espressif.com/sites/default/files/documentation/esp32-wroom-32_datasheet_en.pdf)

[14] datasheet ESP32 [online] [cit. 2020-02-22] Dostupné z: https://cdn.

sparkfun.com/datasheets/IoT/esp32_datasheet_en.pdf (https://cdn.sparkfun.com/datasheets/IoT/esp32_datasheet_en.pdf)

[15] datasheet | ESP32 | [online] | [cit. | 2020-02-22] | Dostupné | z:

https://pdf1.alldatasheet.com/datasheet-pdf/view/1148023/

ESPRESSIF/ESP32.html (https://pdf1.alldatasheet.com/datasheet-pdf/view/1148023/ESPRESSIF/ESP32.html)

[16] datasheet DRV8833 [online] [cit. 2020-02-22] Dostupné z: http://www.

ti.com/lit/ds/symlink/drv8833.pdf

[17] datasheet | IRF4905 | [online] | [cit. | 2020-02-22] | Dostupné | z:

https://www.infineon.com/dgdl/irf4905pbf.pdf?fileId=

5546d462533600a4015355e329b1197e (https://www.infineon.com/dgdl/irf4905pbf.pdf?fileId=5546d462533600a4015355e329b1197e)

[18] datasheet BS170 [online] [cit. 2020-02-22] Dostupné z: https://www.

onsemi.com/pub/Collateral/BS170-D.PDF

[19] datasheet 7805 [online] [cit. 2020-02-22] Dostupné z: https://www.st.

com/resource/en/datasheet/l78.pdf (https://www.st.com/resource/en/datasheet/l78.pdf)

[20] datasheet Step-down [online] [cit. 2020-02-22] Dostupné z: https://

arduino-shop.cz/docs/produkty/0/698/1502185417.pdf

[21] datasheet – mikrospínač [online] [cit. 2020-02-22] Dostupné z: https:

//www.gme.cz/data/attachments/dsh.630-019.1.pdf

| | | 41

### inteligentní servo LX15D

[22] inteligentní serva LX15D [online] [cit. 2020-02-22] Dostupné z: http:

//www.lewansoul.com/product/detail-7.html

42

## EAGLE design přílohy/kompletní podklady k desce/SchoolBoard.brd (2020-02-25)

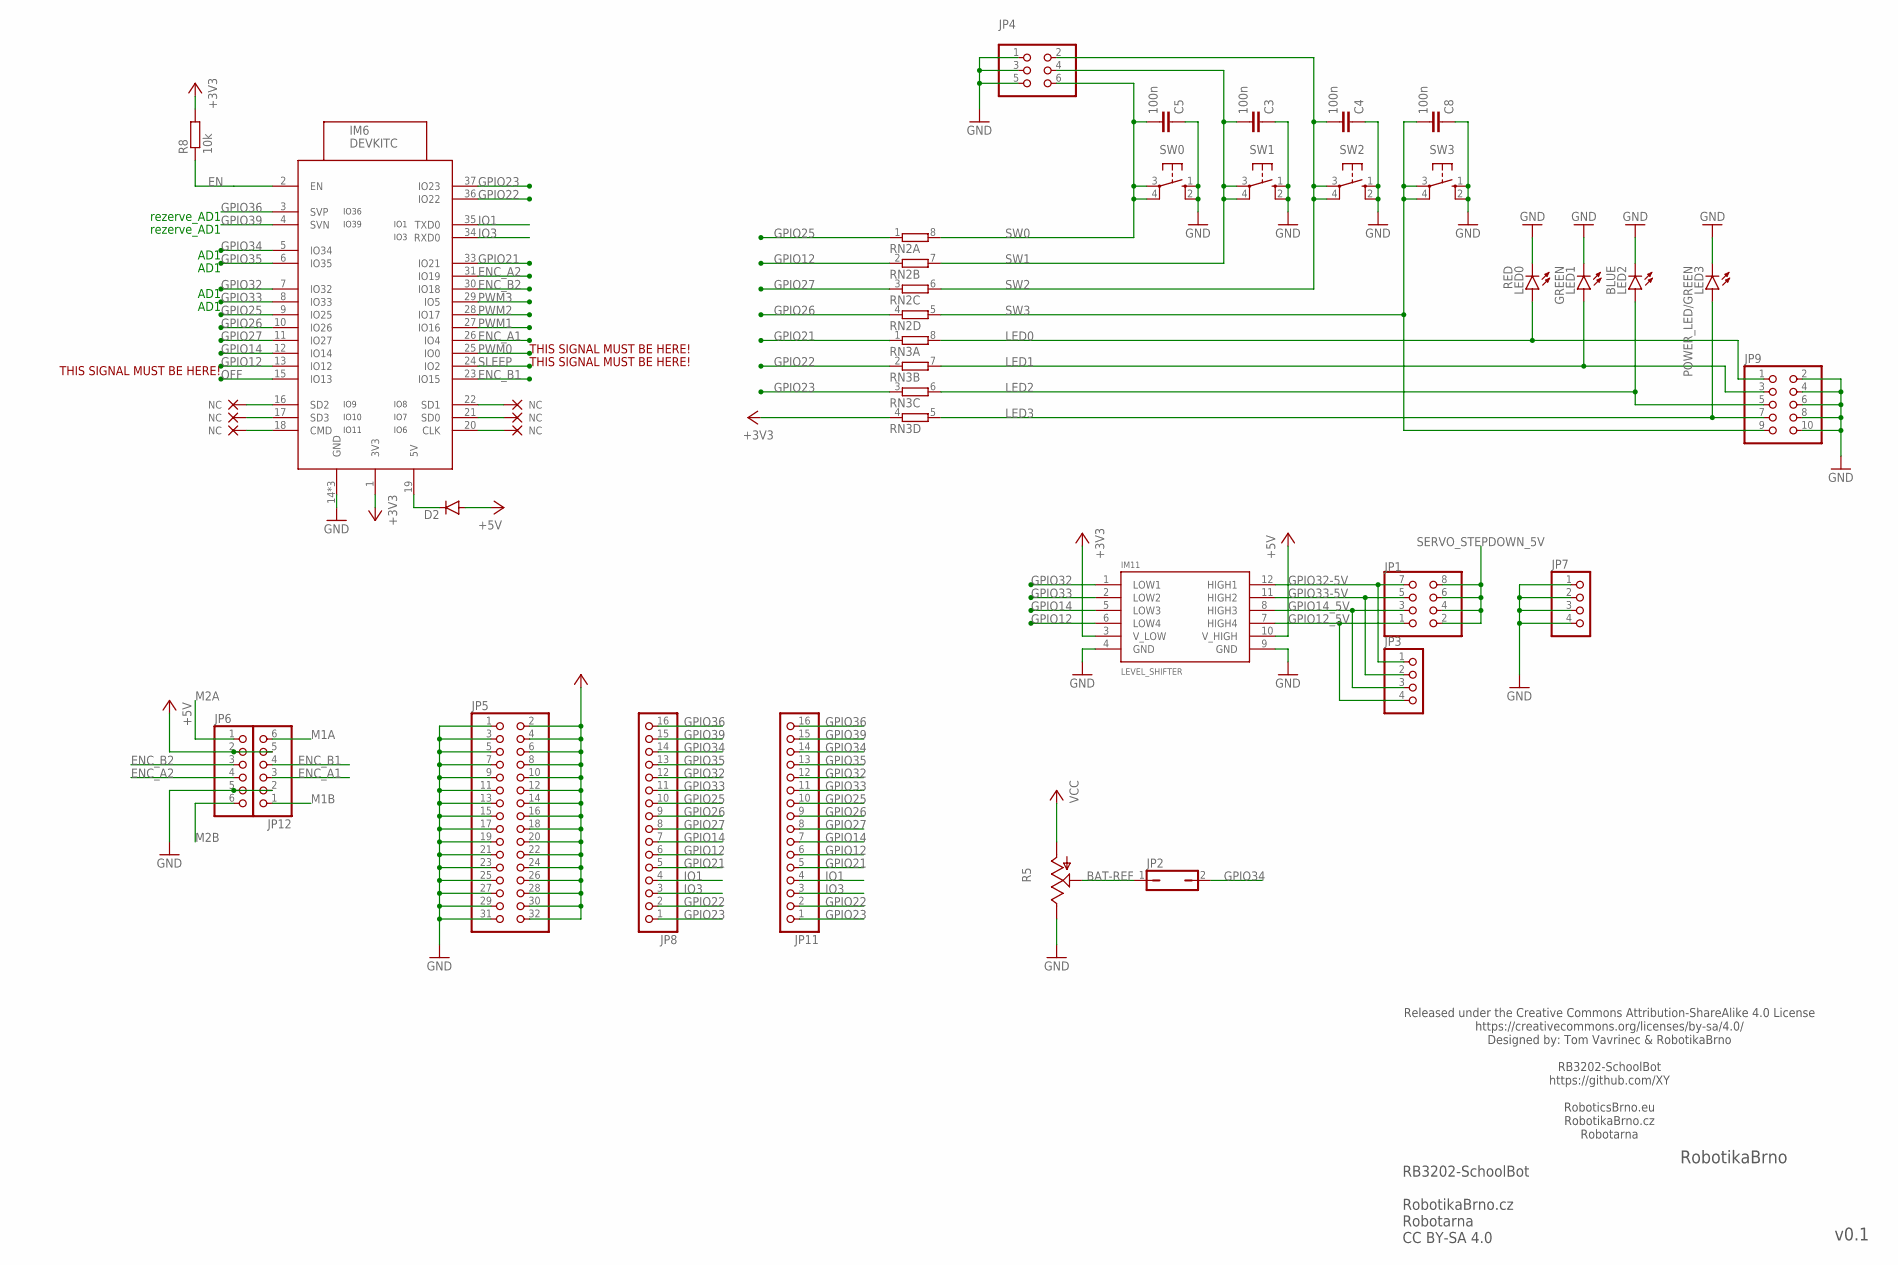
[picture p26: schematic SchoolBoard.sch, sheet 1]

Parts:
C3, C4, C5, C8: 100n; C1206
D2: DIODE-D-7.5; D-7.5
IM6: DEVKITC
IM11: LEVEL_SHIFTER
JP1: PINHD-2X4; 2X04
JP2: JP1Q; JP1
JP3, JP7: PINHD-1X4; 1X04
JP4: PINHD-2X3; 2X03
JP5: PINHD-2X16; 2X16
JP6, JP12: PINHD-1X6; 1X06
JP8, JP11: PINHD-1X16; 1X16
JP9: PINHD-2X5; 2X05
LED0: RED; LED3MM
LED1: GREEN; LED3MM
LED2: BLUE; LED3MM
LED3: POWER_LED/GREEN; LED3MM
R5: TRIM_US-SM-42/43X; SM-42/43X
R8: 10k; R0805
RN2, RN3: 4R-NEXBS8V; EXBS8V
SW0, SW1, SW2, SW3: 10-XX; B3F-10XX

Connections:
+3V3: IM6.1 (3V3), IM11.3 (V_LOW), JP5.2, JP5.4, JP5.6, JP5.8, JP5.10, JP5.12, JP5.14, JP5.16, JP5.18, JP5.20, JP5.22, JP5.24, JP5.26, JP5.28, JP5.30, JP5.32, R8.2, RN3.4 (1); also elsewhere on the board
+5V: D2.A, IM11.10 (V_HIGH), JP6.2, JP12.5; also elsewhere on the board
+5V_ESP: D2.C, IM6.19 (5V)
BAT-REF: JP2.1, R5.2 (S)
EN: IM6.2 (EN), R8.1; also elsewhere on the board
ENC_A1: IM6.26 (IO4), JP12.3
ENC_A2: IM6.31 (IO19), JP6.4
ENC_B1: IM6.23 (IO15), JP12.4
ENC_B2: IM6.30 (IO18), JP6.3
GND: C3.1, C4.1, C5.1, C8.1, IM6.14 (GND), IM6.32 (GND), IM6.38 (GND), IM11.4 (GND), IM11.9 (GND), JP4.1, JP4.3, JP4.5, JP5.1, JP5.3, JP5.5, JP5.7, JP5.9, JP5.11, JP5.13, JP5.15, JP5.17, JP5.19, JP5.21, JP5.23, JP5.25, JP5.27, JP5.29, JP5.31, JP6.5, JP7.1, JP7.2, JP7.3, JP7.4, JP9.2, JP9.4, JP9.6, JP9.8, JP9.10, JP12.2, LED0.K (C), LED1.K (C), LED2.K (C), LED3.K (C), R5.3 (E), SW0.1 (S), SW0.2 (S1), SW1.1 (S), SW1.2 (S1), SW2.1 (S), SW2.2 (S1), SW3.1 (S), SW3.2 (S1); also elsewhere on the board
GPIO12: IM6.13 (IO12), IM11.6 (LOW4), JP8.6, JP11.6, RN2.2 (1)
GPIO12_5V: IM11.7 (HIGH4), JP1.1, JP3.4
GPIO14: IM6.12 (IO14), IM11.5 (LOW3), JP8.7, JP11.7
GPIO14_5V: IM11.8 (HIGH3), JP1.3, JP3.3
GPIO21: IM6.33 (IO21), JP8.5, JP11.5, RN3.1
GPIO22: IM6.36 (IO22), JP8.2, JP11.2, RN3.2 (1)
GPIO23: IM6.37 (IO23), JP8.1, JP11.1, RN3.3 (1)
GPIO25: IM6.9 (IO25), JP8.10, JP11.10, RN2.1
GPIO26: IM6.10 (IO26), JP8.9, JP11.9, RN2.4 (1)
GPIO27: IM6.11 (IO27), JP8.8, JP11.8, RN2.3 (1)
GPIO32: IM6.7 (IO32), IM11.1 (LOW1), JP8.12, JP11.12
GPIO32-5V: IM11.12 (HIGH1), JP1.7, JP3.1
GPIO33: IM6.8 (IO33), IM11.2 (LOW2), JP8.11, JP11.11
GPIO33-5V: IM11.11 (HIGH2), JP1.5, JP3.2
GPIO34: IM6.5 (IO34), JP2.2, JP8.14, JP11.14
GPIO35: IM6.6 (IO35), JP8.13, JP11.13; also elsewhere on the board
GPIO36: IM6.3 (SVP), JP8.16, JP11.16
GPIO39: IM6.4 (SVN), JP8.15, JP11.15
IO1: IM6.35 (TXD0), JP8.4, JP11.4
IO3: IM6.34 (RXD0), JP8.3, JP11.3
IO9_NC: IM6.16 (SD2)
IO9_NC1: IM6.20 (CLK)
IO10_NC: IM6.17 (SD3)
IO10_NC1: IM6.21 (SD0)
IO11_NC: IM6.18 (CMD)
IO11_NC1: IM6.22 (SD1)
LED0: JP9.1, LED0.A, RN3.8 (2)
LED1: JP9.3, LED1.A, RN3.7 (2)
LED2: JP9.5, LED2.A, RN3.6 (2)
LED3: JP9.7, LED3.A, RN3.5 (2)
M1A: JP12.6; also elsewhere on the board
M1B: JP12.1; also elsewhere on the board
M2A: JP6.1; also elsewhere on the board
M2B: JP6.6; also elsewhere on the board
OFF: IM6.15 (IO13); also elsewhere on the board
PWM0: IM6.25 (IO0); also elsewhere on the board
PWM1: IM6.27 (IO16); also elsewhere on the board
PWM2: IM6.28 (IO17); also elsewhere on the board
PWM3: IM6.29 (IO5); also elsewhere on the board
SERVO_STEPDOWN_5V: JP1.2, JP1.4, JP1.6, JP1.8; also elsewhere on the board
SLEEP: IM6.24 (IO2); also elsewhere on the board
SW0: C5.2, JP4.6, RN2.8 (2), SW0.3, SW0.4 (P1)
SW1: C3.2, JP4.4, RN2.7 (2), SW1.3, SW1.4 (P1)
SW2: C4.2, JP4.2, RN2.6 (2), SW2.3, SW2.4 (P1)
SW3: C8.2, JP9.9, RN2.5 (2), SW3.3, SW3.4 (P1)
VCC: R5.1 (A); also elsewhere on the board

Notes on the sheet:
AD1
rezerve_AD1
RB3202-SchoolBot RobotikaBrno.cz Robotarna CC BY-SA 4.0
RobotikaBrno
v0.1
Released under the Creative Commons Attribution-ShareAlike 4.0 License https://creativecommons.org/licenses/by-sa/4.0/ Designed by: Tom Vavrinec & RobotikaBrno RB3202-SchoolBot https://github.com/XY RoboticsBrno.eu RobotikaBrno.cz Robotarna
THIS SIGNAL MUST BE HERE!

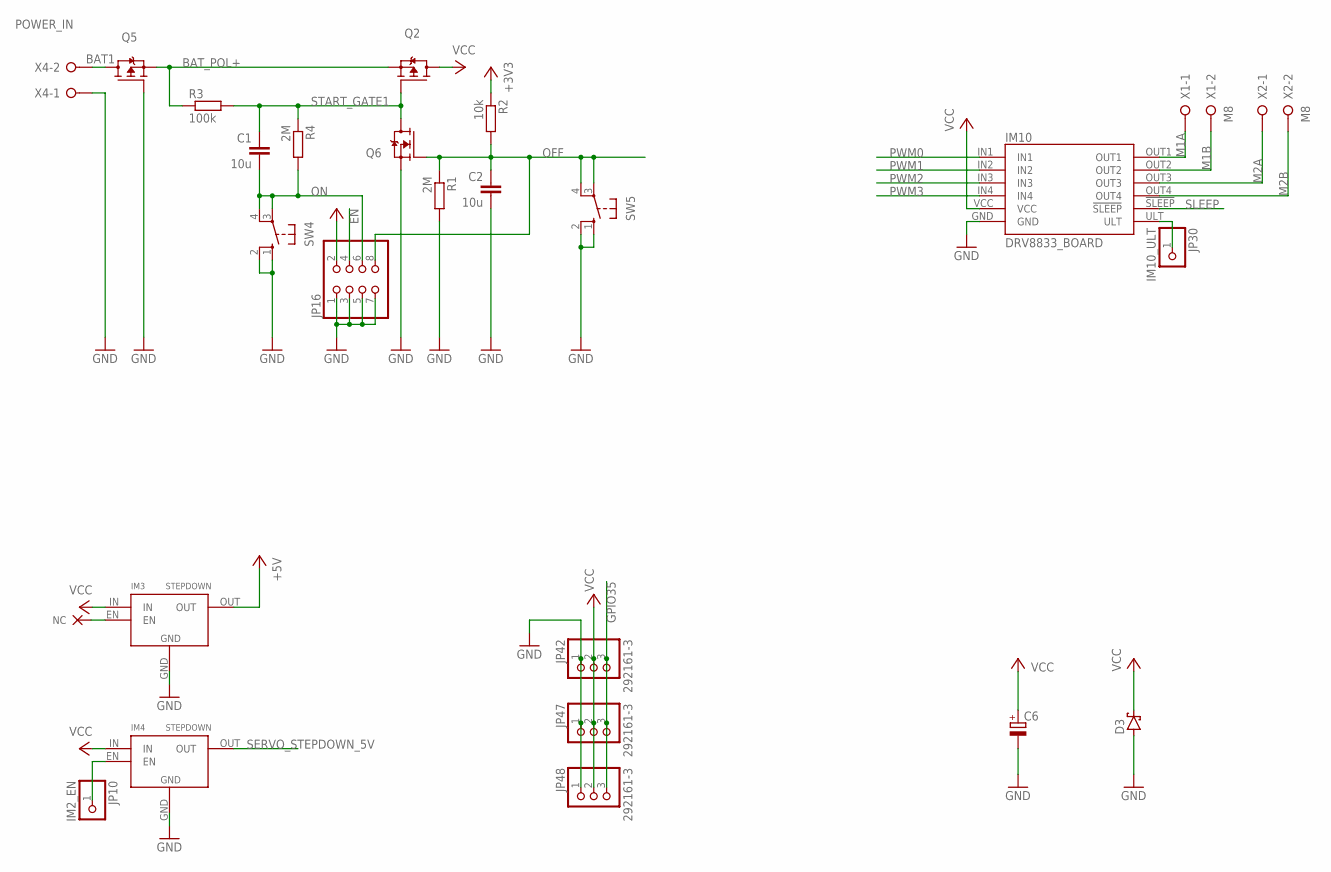
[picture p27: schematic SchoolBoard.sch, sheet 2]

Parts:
C1, C2: 10u; C1206
C6: CPOL-EUE5-10.5; E5-10,5
D3: SCHOTTKY-DIODEF126Z12; F126Z12
IM3, IM4: STEPDOWN
IM10: DRV8833_BOARD; PINHEAD
JP10: IM2_EN; 1X01
JP16: PINHD-2X4; 2X04
JP30: IM10_ULT; 1X01
JP42, JP47, JP48: 292161-3
Q2, Q5: P-MOSFET-TO220V; TO220V
Q6: N-MOSFET-SOT23-GSD; SOT23
R1: 2M; R0805
R2: 10k; R0805
R3: 100k; R0805
R4: 2M; M0805
SW4, SW5: 10-XX; B3F-10XX
X1, X2: M8; W237-132
X4: POWER_IN; W237-132

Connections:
+3V3: R2.1; also elsewhere on the board
+5V: IM3.OUT, JP16.2; also elsewhere on the board
BAT1: Q5.2 (D), X4.2
BAT_POL+: Q2.3 (S), Q5.3 (S), R3.1
EN: JP16.4; also elsewhere on the board
GND: C2.2, C6.-, D3.A, IM3.GND, IM4.GND, IM10.GND, JP16.1, JP16.3, JP16.5, JP16.7, JP42.1, JP47.1, JP48.1, Q5.1 (G), Q6.2 (S), R1.2, SW4.1 (S), SW4.2 (S1), SW5.1 (S), SW5.2 (S1), X4.1; also elsewhere on the board
GPIO35: JP42.3, JP47.3, JP48.3; also elsewhere on the board
IO9_NC2: IM3.EN
M1A: IM10.OUT1, X1.1; also elsewhere on the board
M1B: IM10.OUT2, X1.2; also elsewhere on the board
M2A: IM10.OUT3, X2.1; also elsewhere on the board
M2B: IM10.OUT4, X2.2; also elsewhere on the board
unnamed: IM10.ULT, JP30.1
OFF: C2.1, JP16.8, Q6.1 (G), R1.1, R2.2, SW5.3, SW5.4 (P1); also elsewhere on the board
ON: C1.2, JP16.6, R4.2, SW4.3, SW4.4 (P1)
PWM0: IM10.IN1; also elsewhere on the board
PWM1: IM10.IN2; also elsewhere on the board
PWM2: IM10.IN3; also elsewhere on the board
PWM3: IM10.IN4; also elsewhere on the board
SERVO_STEPDOWN_5V: IM4.OUT; also elsewhere on the board
SLEEP: IM10.!SLEEP; also elsewhere on the board
START_GATE1: C1.1, Q2.1 (G), Q6.3 (D), R3.2, R4.1
STEP2_EN1: IM4.EN, JP10.1
VCC: C6.+, D3.C, IM3.IN, IM4.IN, IM10.VCC, JP42.2, JP47.2, JP48.2, Q2.2 (D); also elsewhere on the board

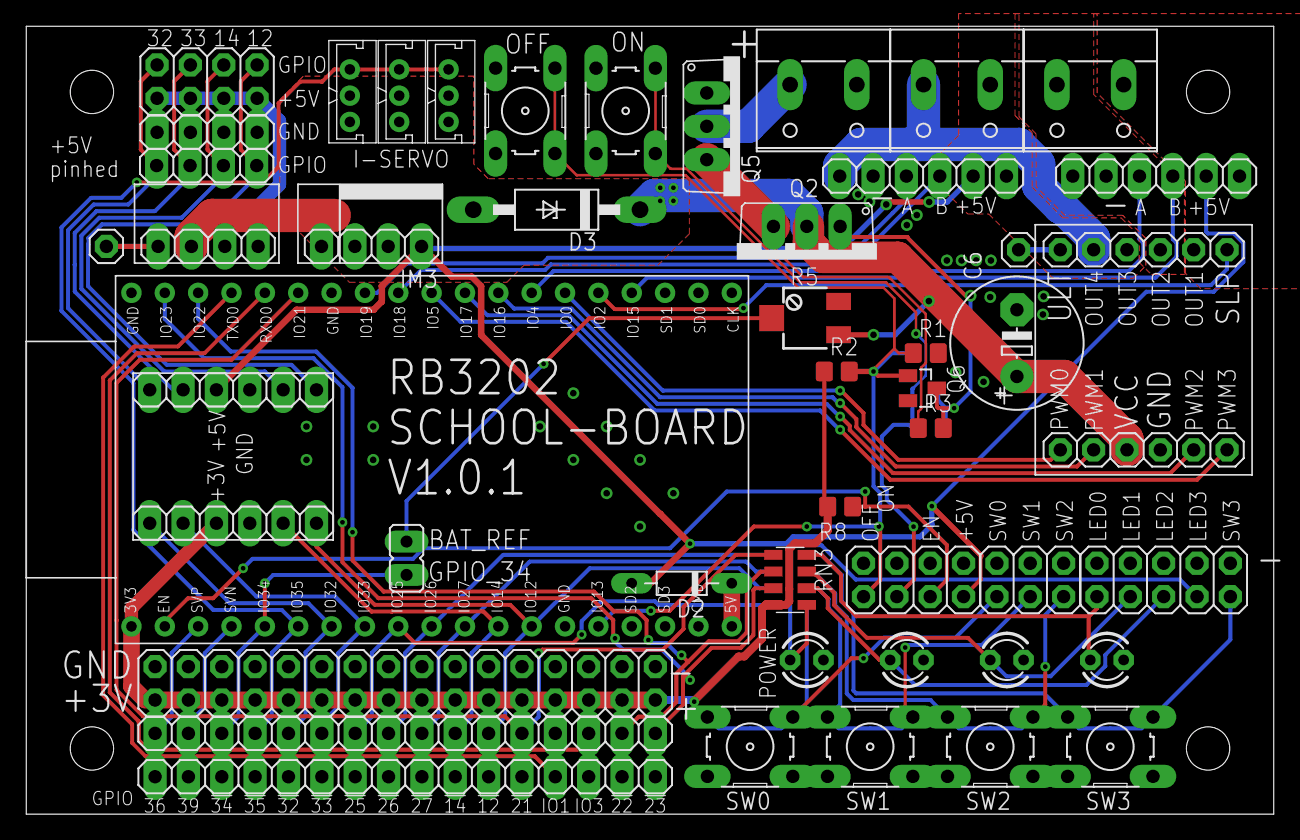
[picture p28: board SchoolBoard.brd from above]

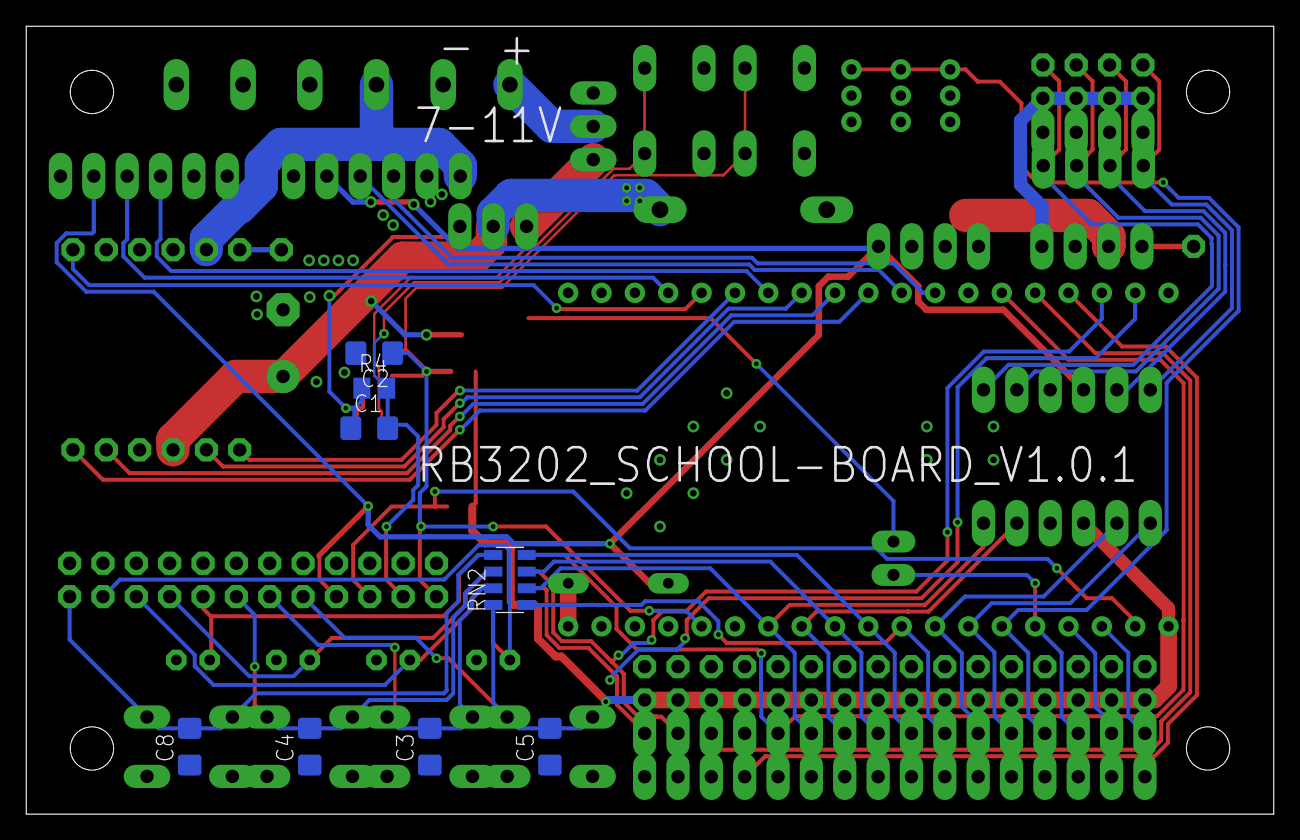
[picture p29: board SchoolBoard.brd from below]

Board: 2 copper layers, 95.0 x 60.0 mm, 55 parts (8 on the bottom side), 56 nets.

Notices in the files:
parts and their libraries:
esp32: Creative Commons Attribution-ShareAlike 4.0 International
